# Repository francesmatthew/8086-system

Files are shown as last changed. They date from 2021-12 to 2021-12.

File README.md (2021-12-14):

# 8086-system
8086-based system, designed in KiCAD

3D Render of PCB

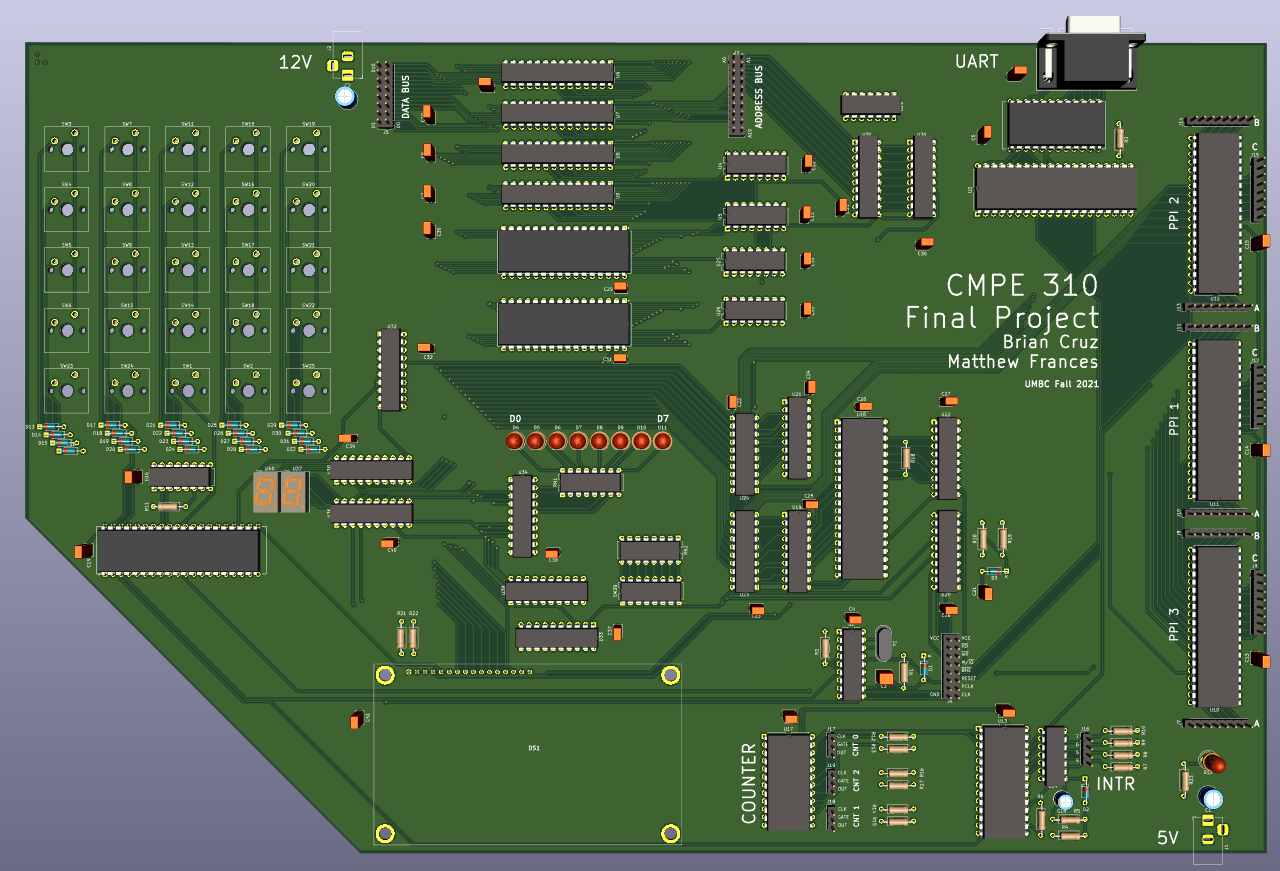
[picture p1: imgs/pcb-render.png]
PCB 3D Render


PCB Overview (fill zones not shown)

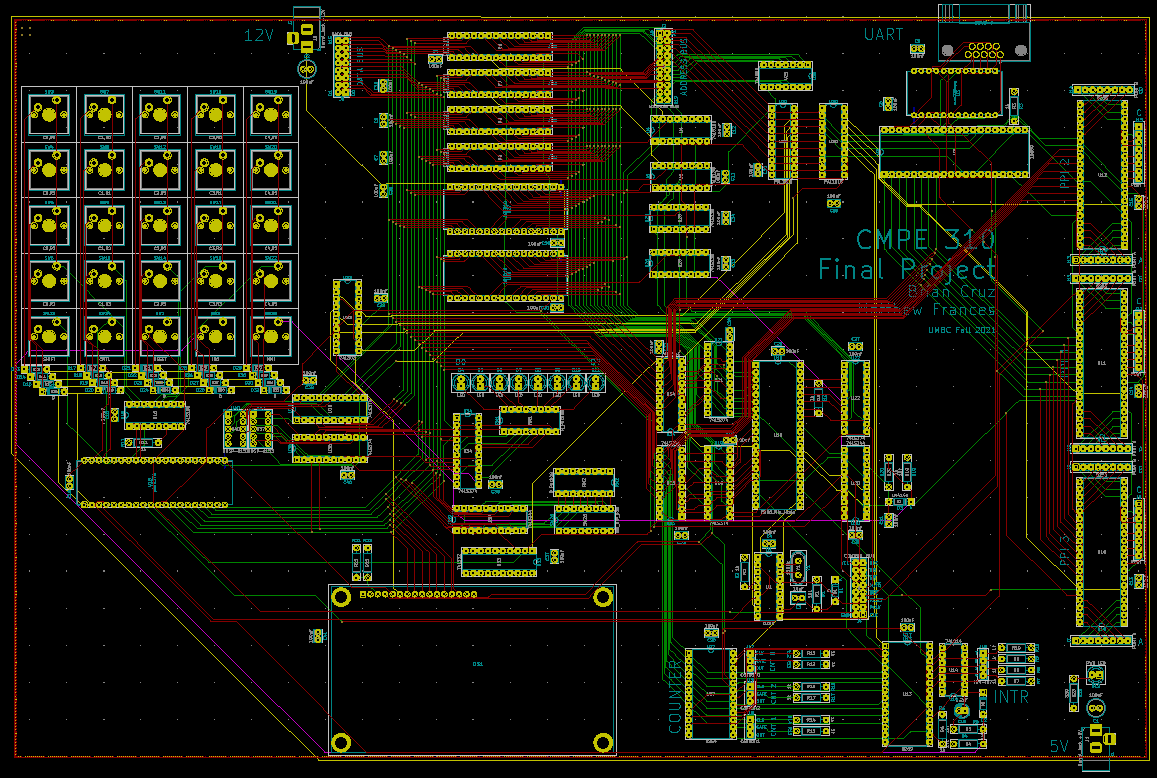
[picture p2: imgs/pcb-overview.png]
PCB Overview


Root Sheet

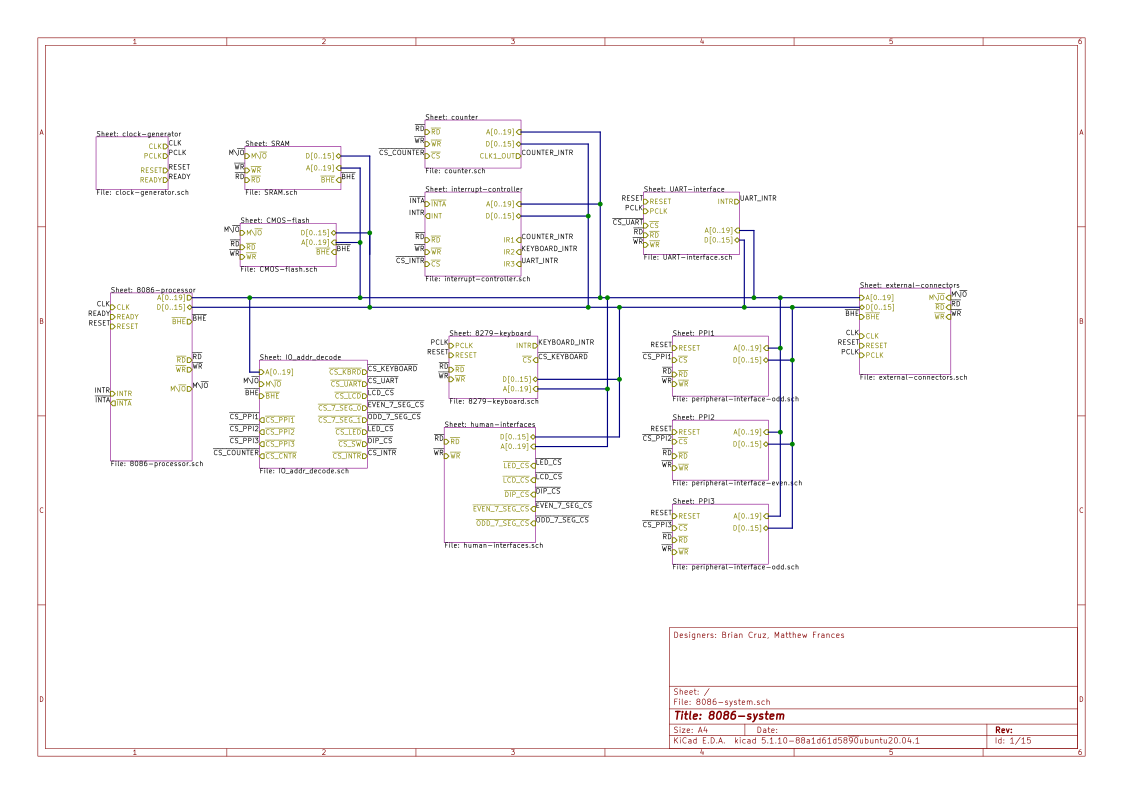
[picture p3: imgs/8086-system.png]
Root Sheet


8086 Processor and Bus Demultiplexing Logic

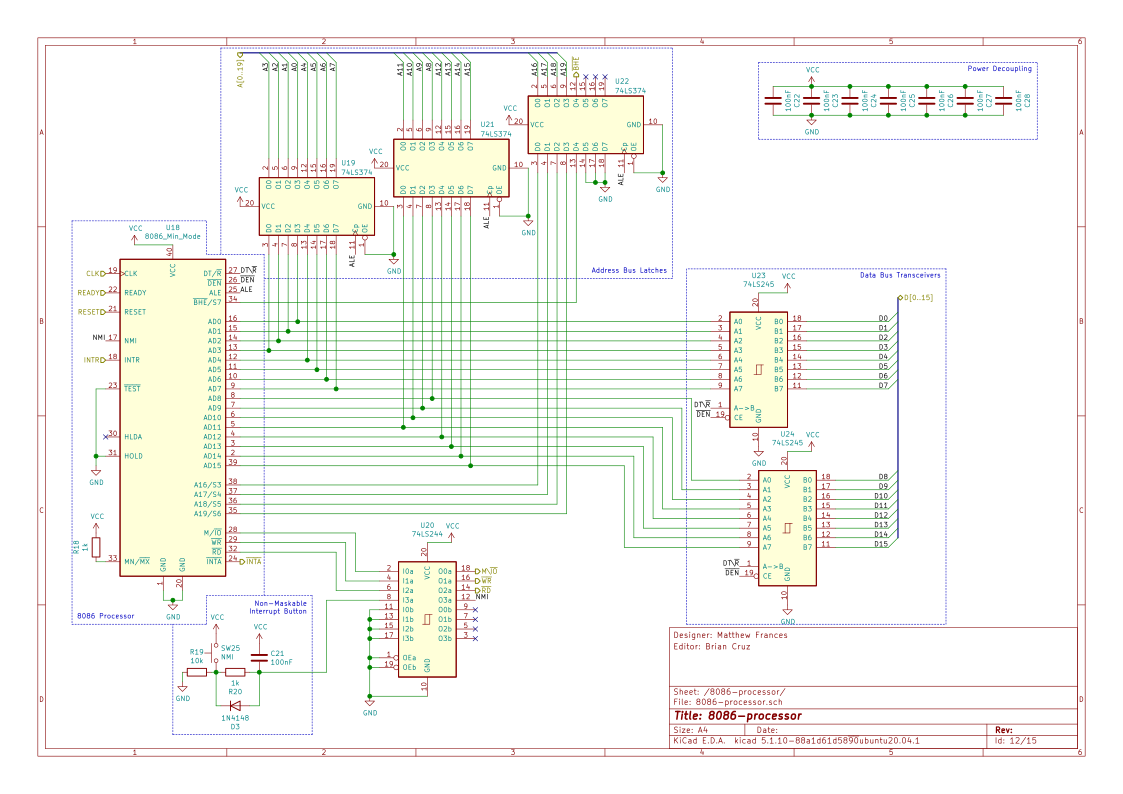
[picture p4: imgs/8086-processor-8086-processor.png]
8086 Processor


28F010 CMOS Flash

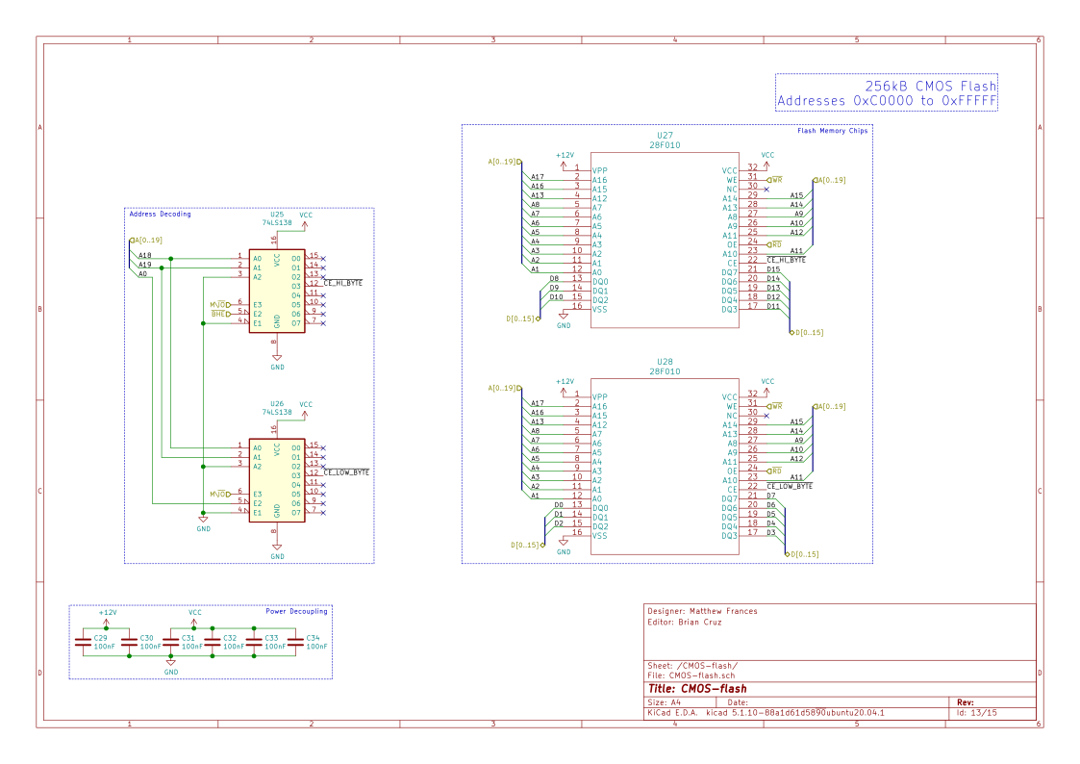
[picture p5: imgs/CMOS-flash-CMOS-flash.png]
28F010 CMOS Flash


CY7C199 SRAM

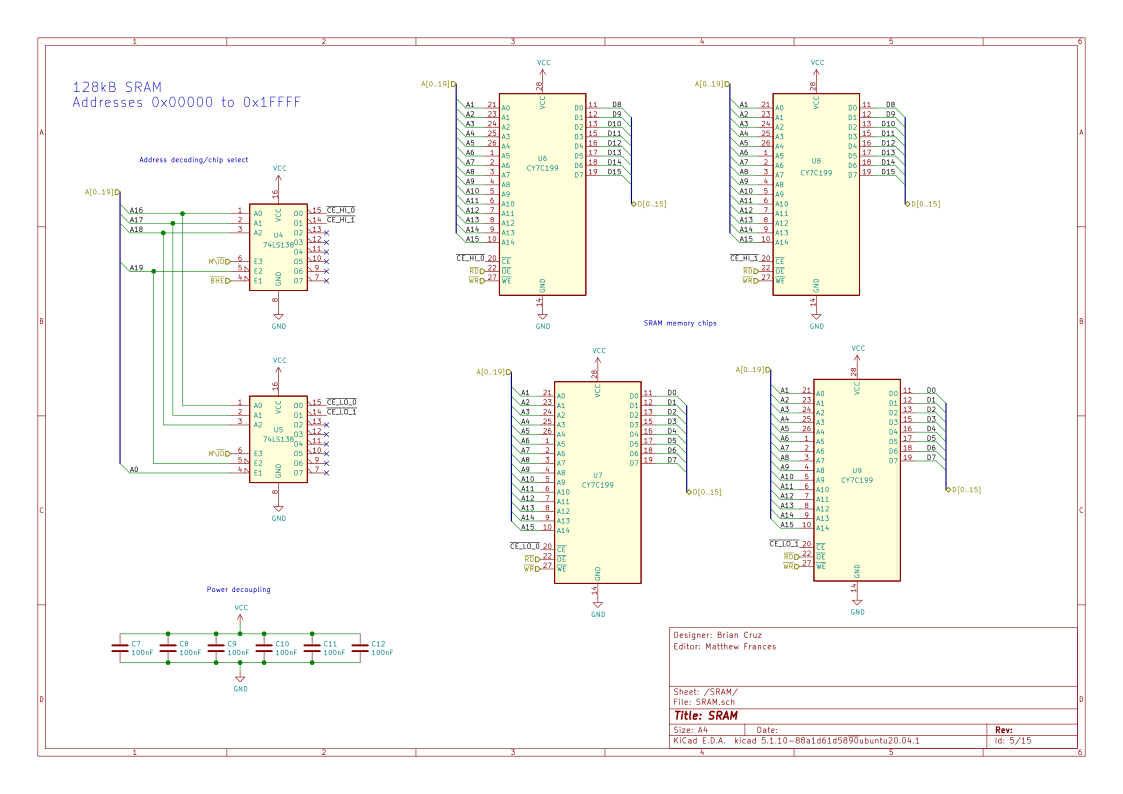
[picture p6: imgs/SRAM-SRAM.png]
CY7C199 SRAM


8284A Clock Generator

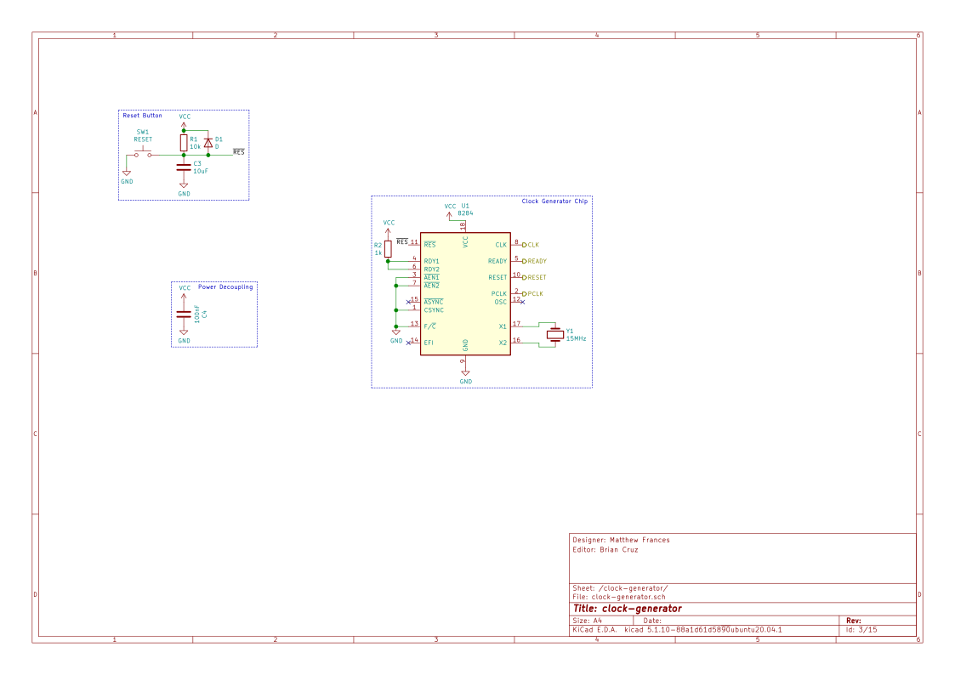
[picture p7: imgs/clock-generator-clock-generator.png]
8284A Clock Generator


PAL16L8 I/O Address Decoding

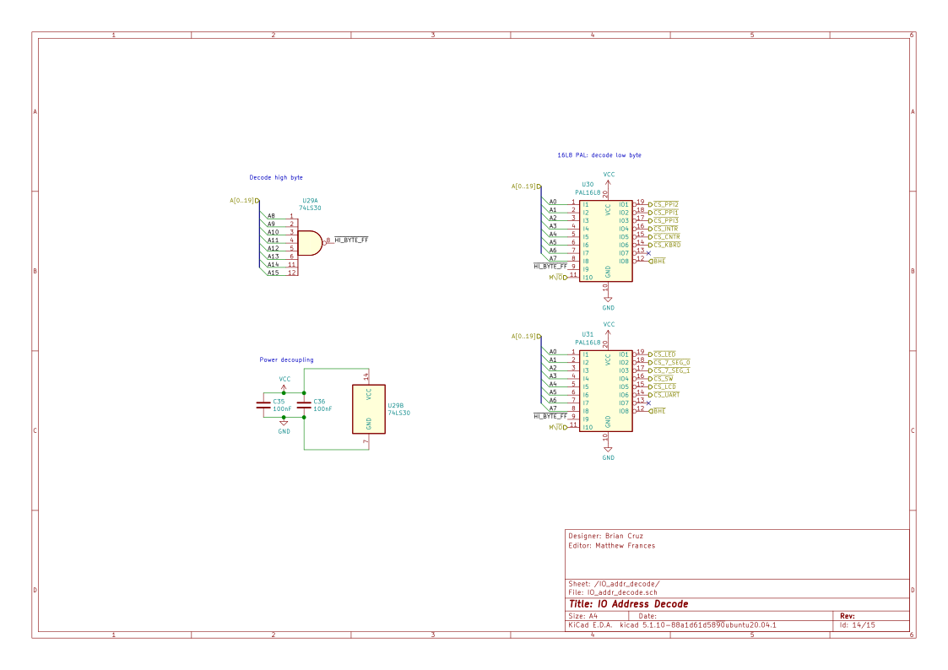
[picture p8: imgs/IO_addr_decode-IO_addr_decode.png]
PAL16L8 I/O Address Decoding


8259 Interrupt Controller

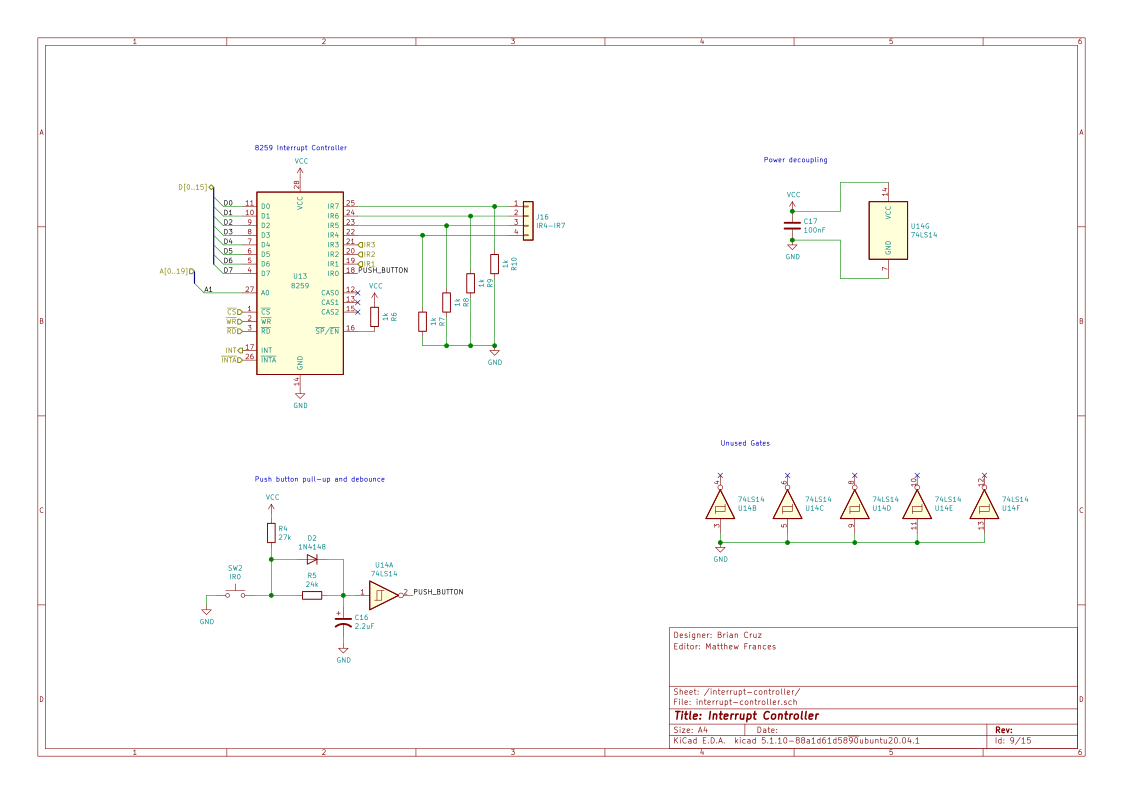
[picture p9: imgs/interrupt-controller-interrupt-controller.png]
8259 Interrupt Controller


8254 Counter

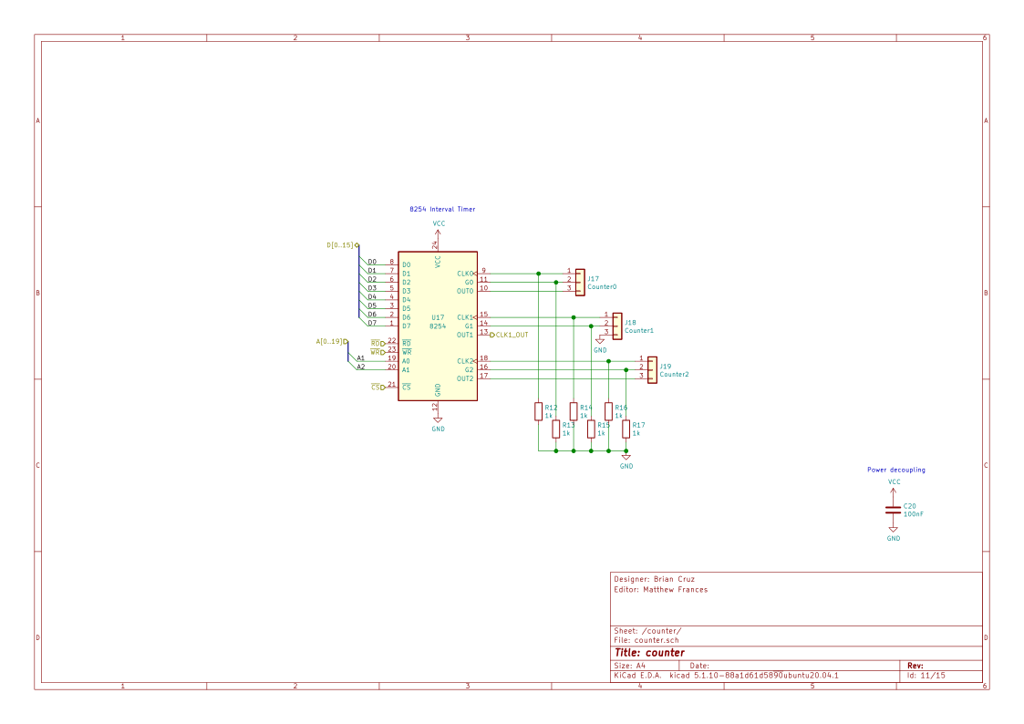
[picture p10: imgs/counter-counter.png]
8254 Counter


8279 Keyboard

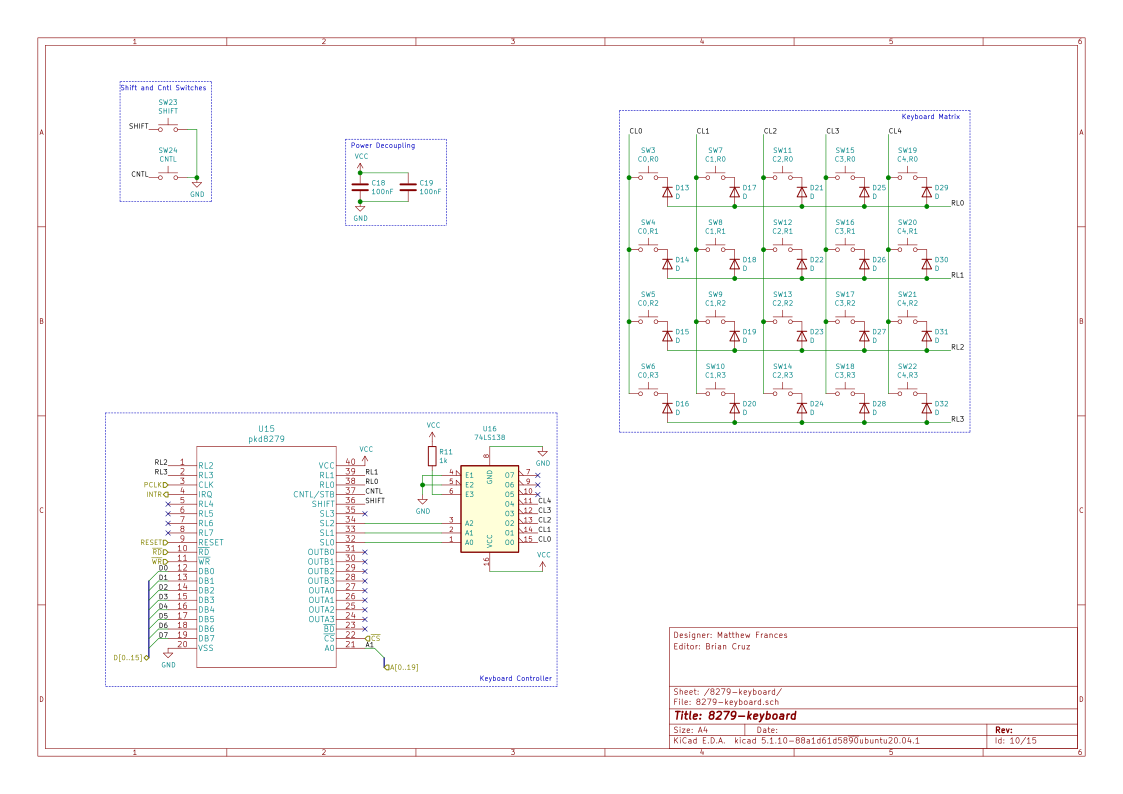
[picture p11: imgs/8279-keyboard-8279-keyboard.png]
8279 Keyboard


16550 UART Interface

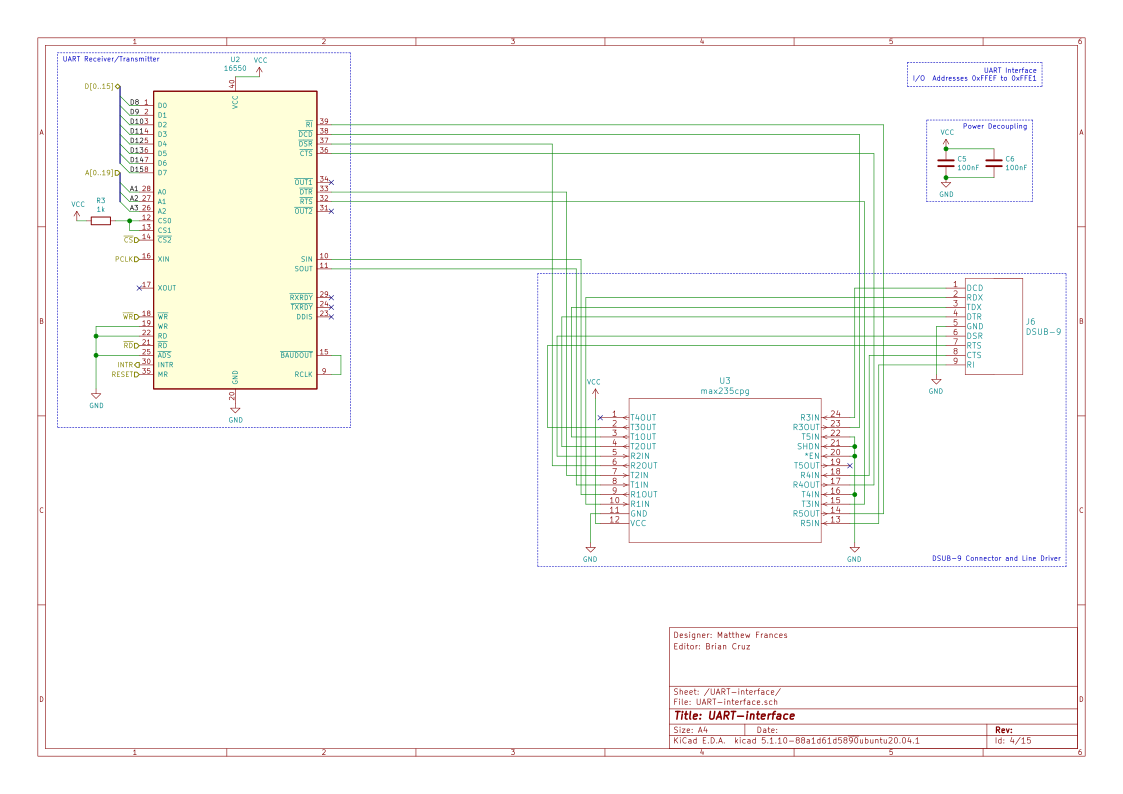
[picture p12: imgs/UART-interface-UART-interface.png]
16550 UART Interface


8255 Programmable Peripheral Interface 1

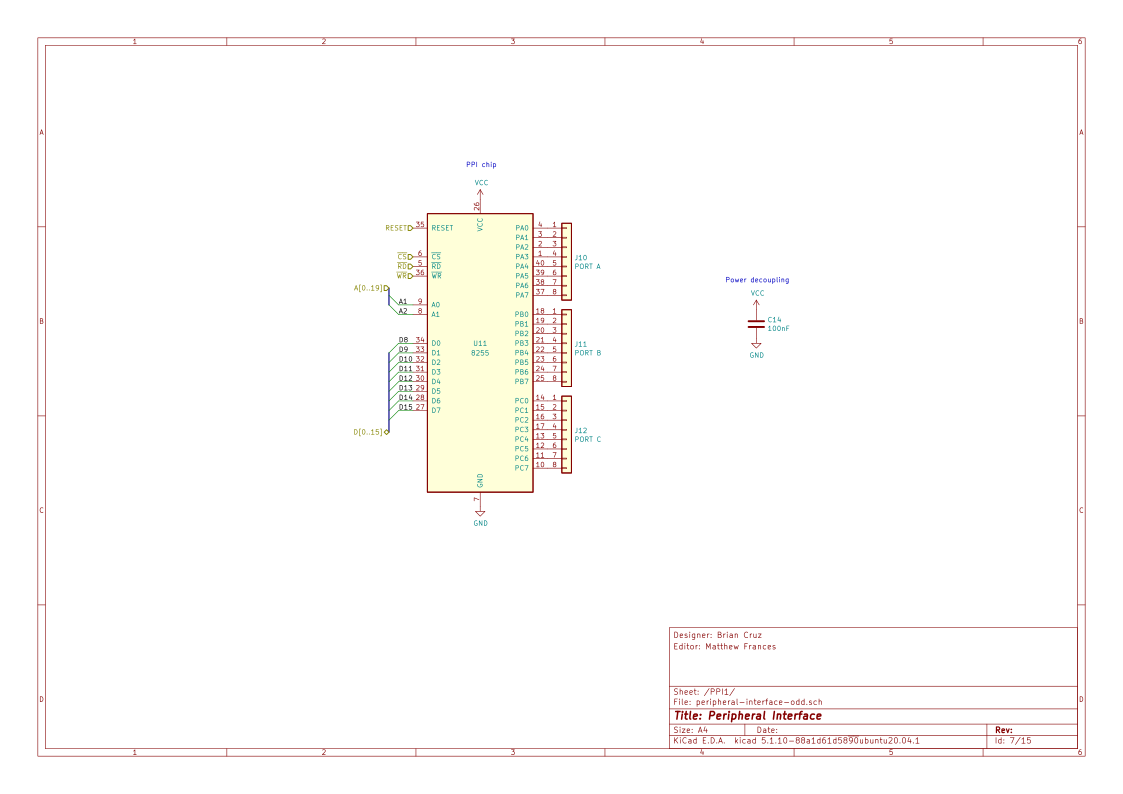
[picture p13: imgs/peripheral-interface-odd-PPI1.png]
8255 Programmable Peripheral Interface 1


8255 Programmable Peripheral Interface 2

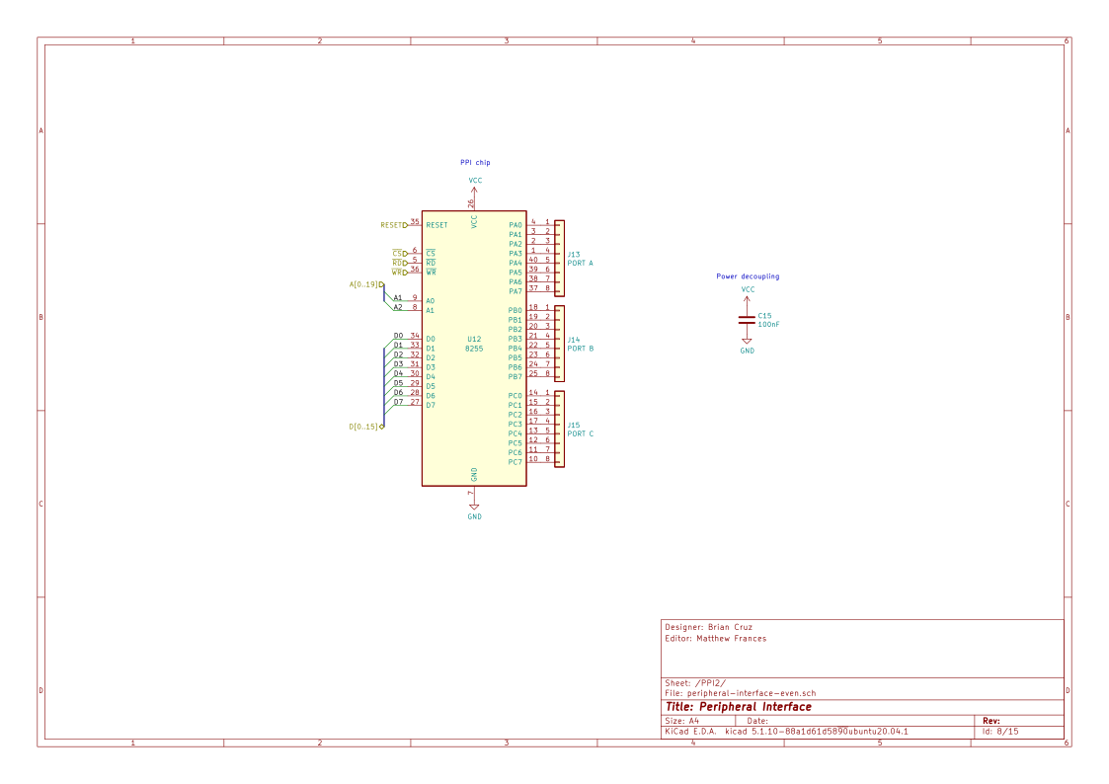
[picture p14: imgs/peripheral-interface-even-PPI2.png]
8255 Programmable Peripheral Interface 2


8255 Programmable Peripheral Interface 3

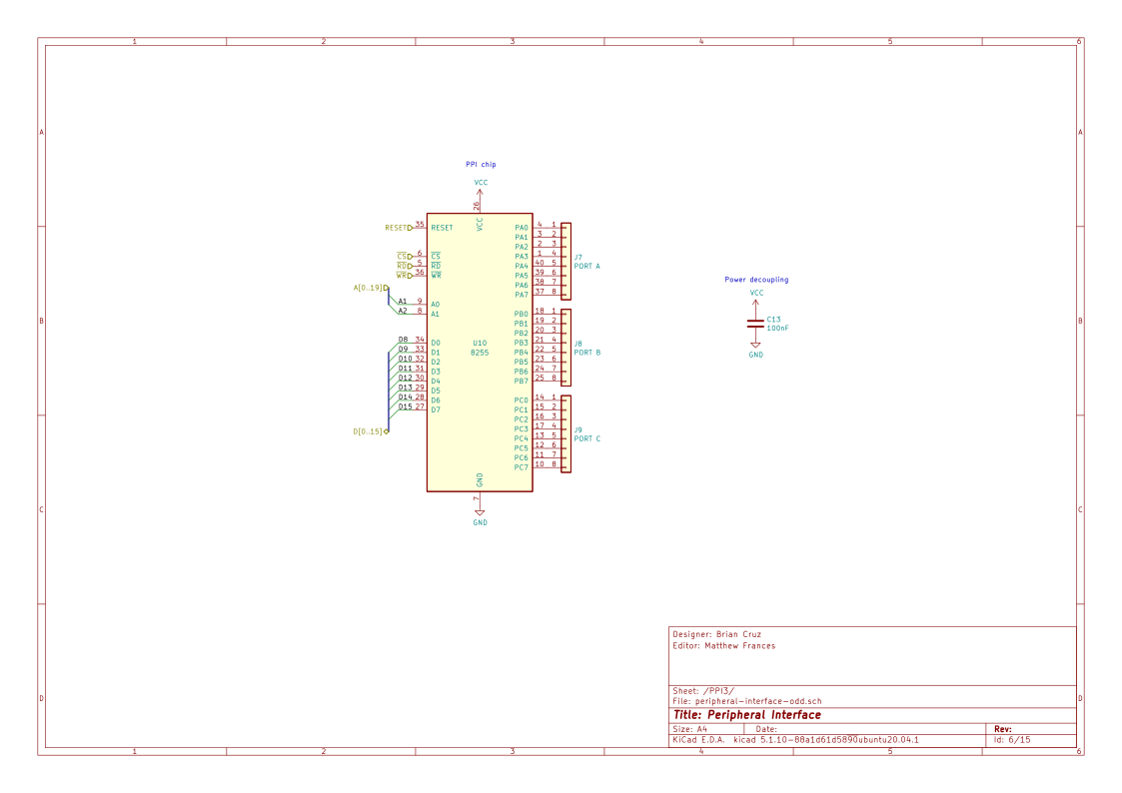
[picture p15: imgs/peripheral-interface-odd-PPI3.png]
8255 Programmable Peripheral Interface 3


LCD, 7-Segment Displays, LEDs, DIP Switches

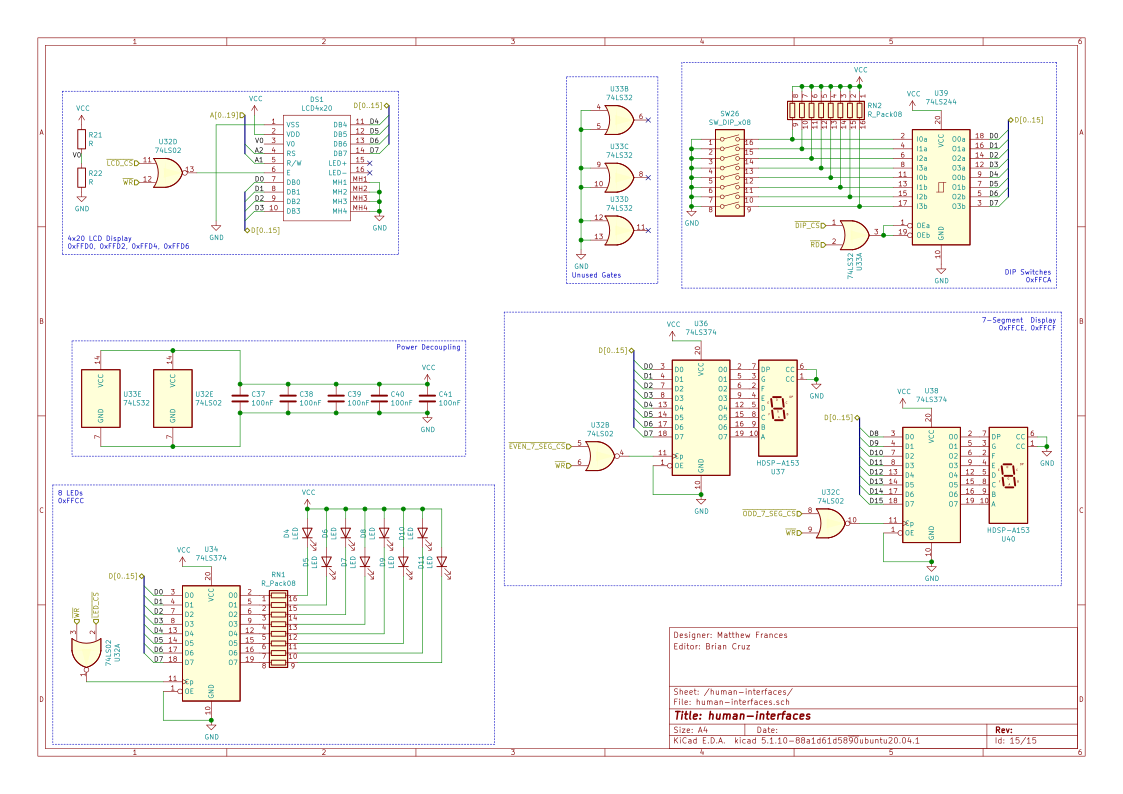
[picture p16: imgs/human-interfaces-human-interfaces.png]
LCD, 7-Segment Displays, LEDs, DIP Switches


Bus Headers, Power Connections

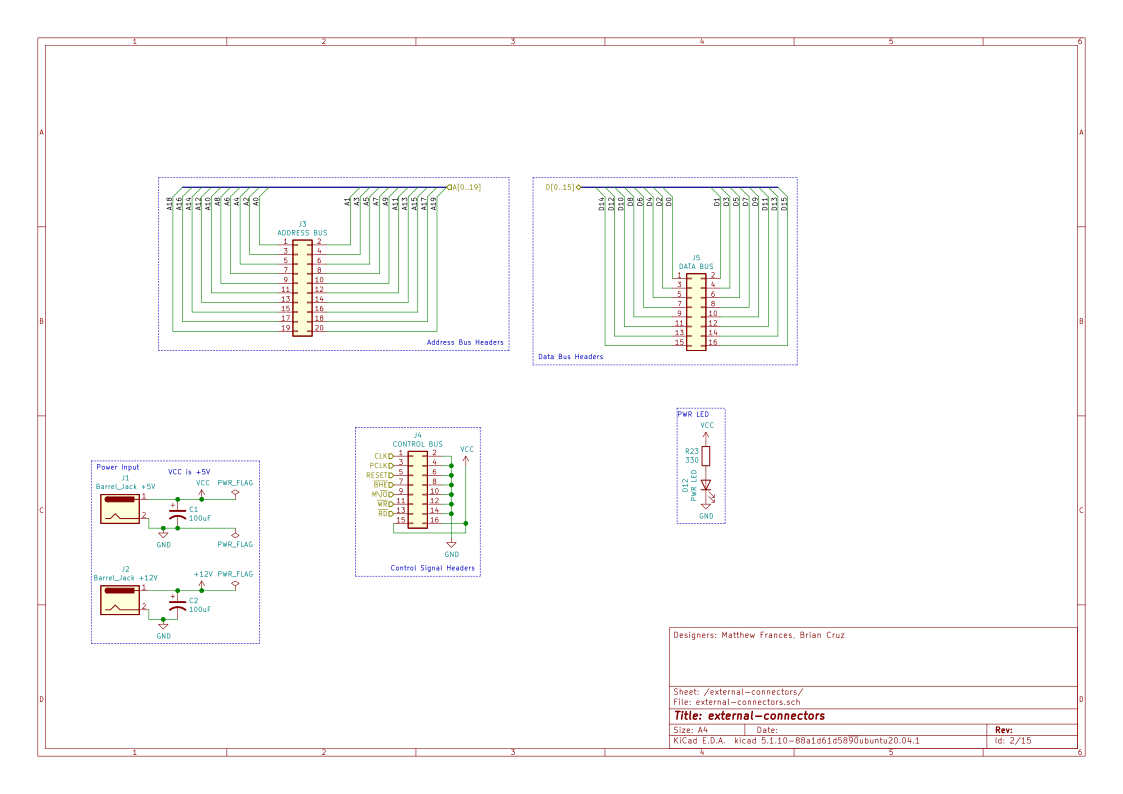
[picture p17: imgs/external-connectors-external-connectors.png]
Bus Headers, Power Connections


Front Copper Layer

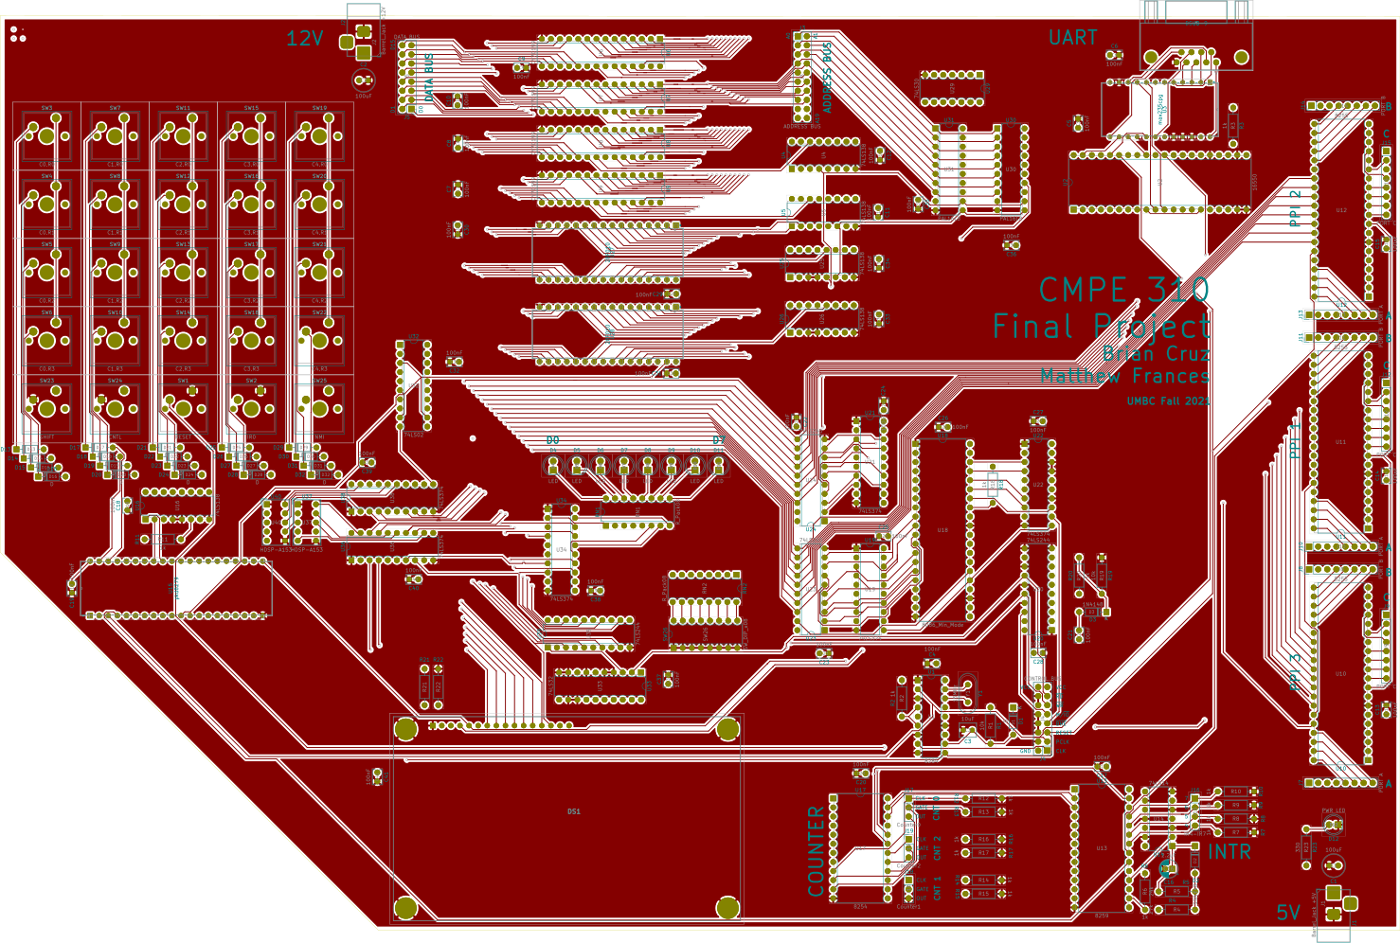
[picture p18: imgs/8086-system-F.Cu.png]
Front Copper Layer


Inner Copper Layer 1

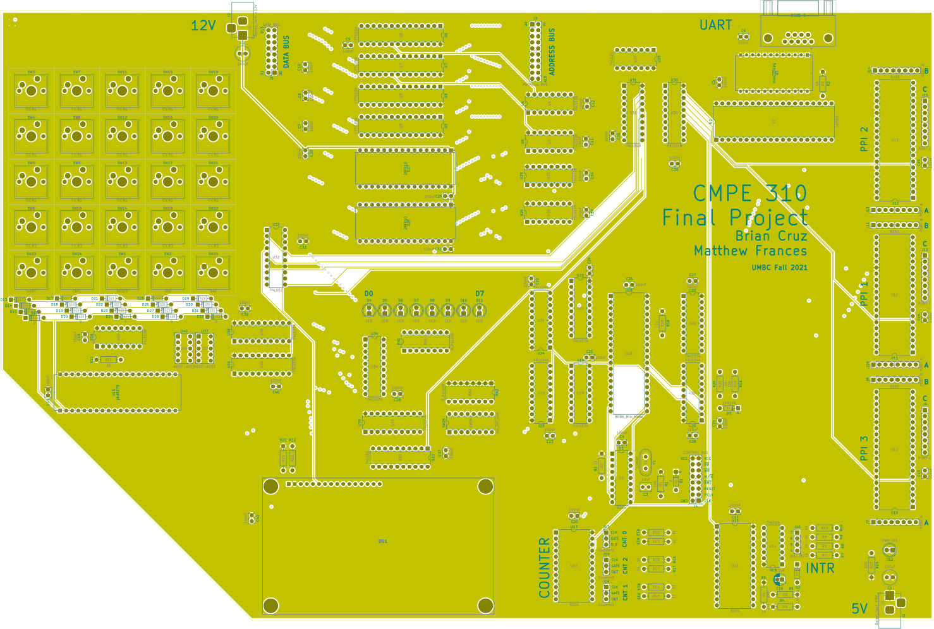
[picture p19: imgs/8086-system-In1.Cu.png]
Inner Copper Layer 1


Inner Copper Layer 2

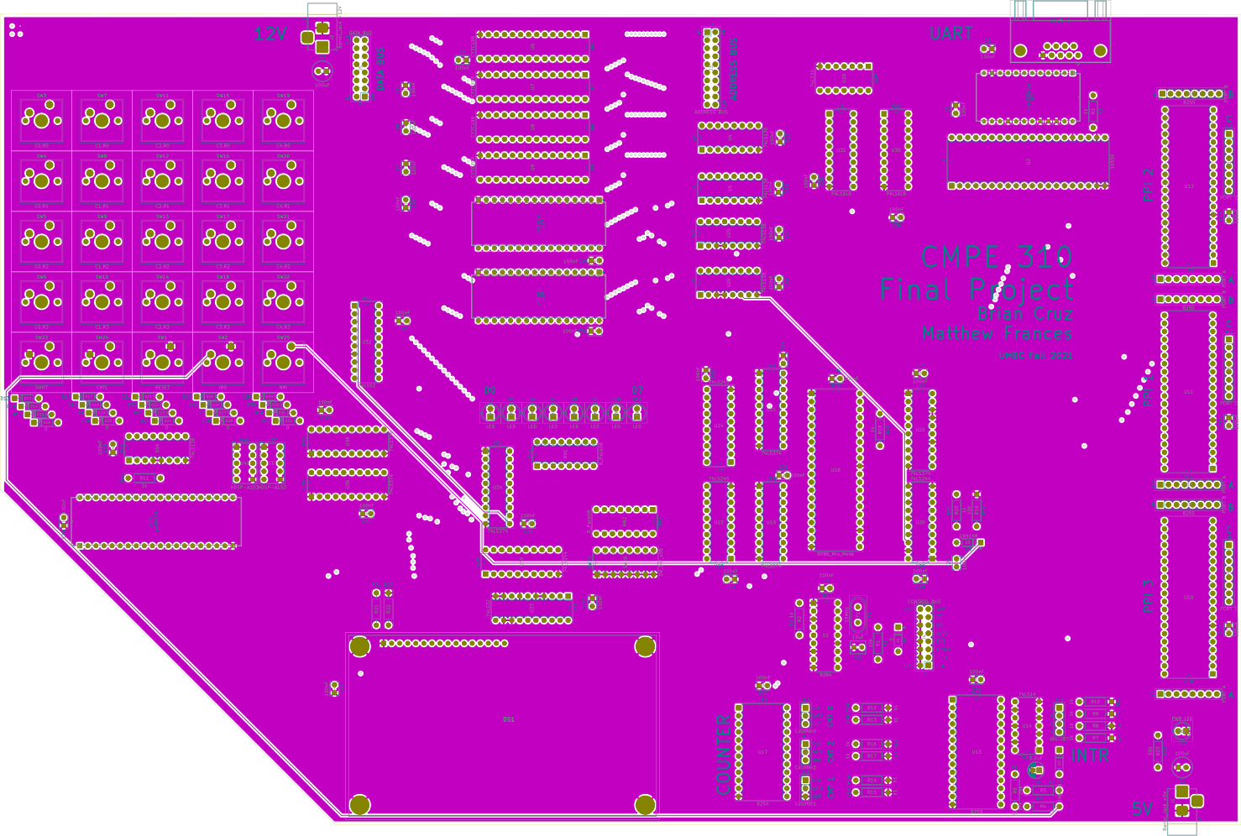
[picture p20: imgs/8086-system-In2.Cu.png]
Inner Copper Layer 2


Back Copper Layer

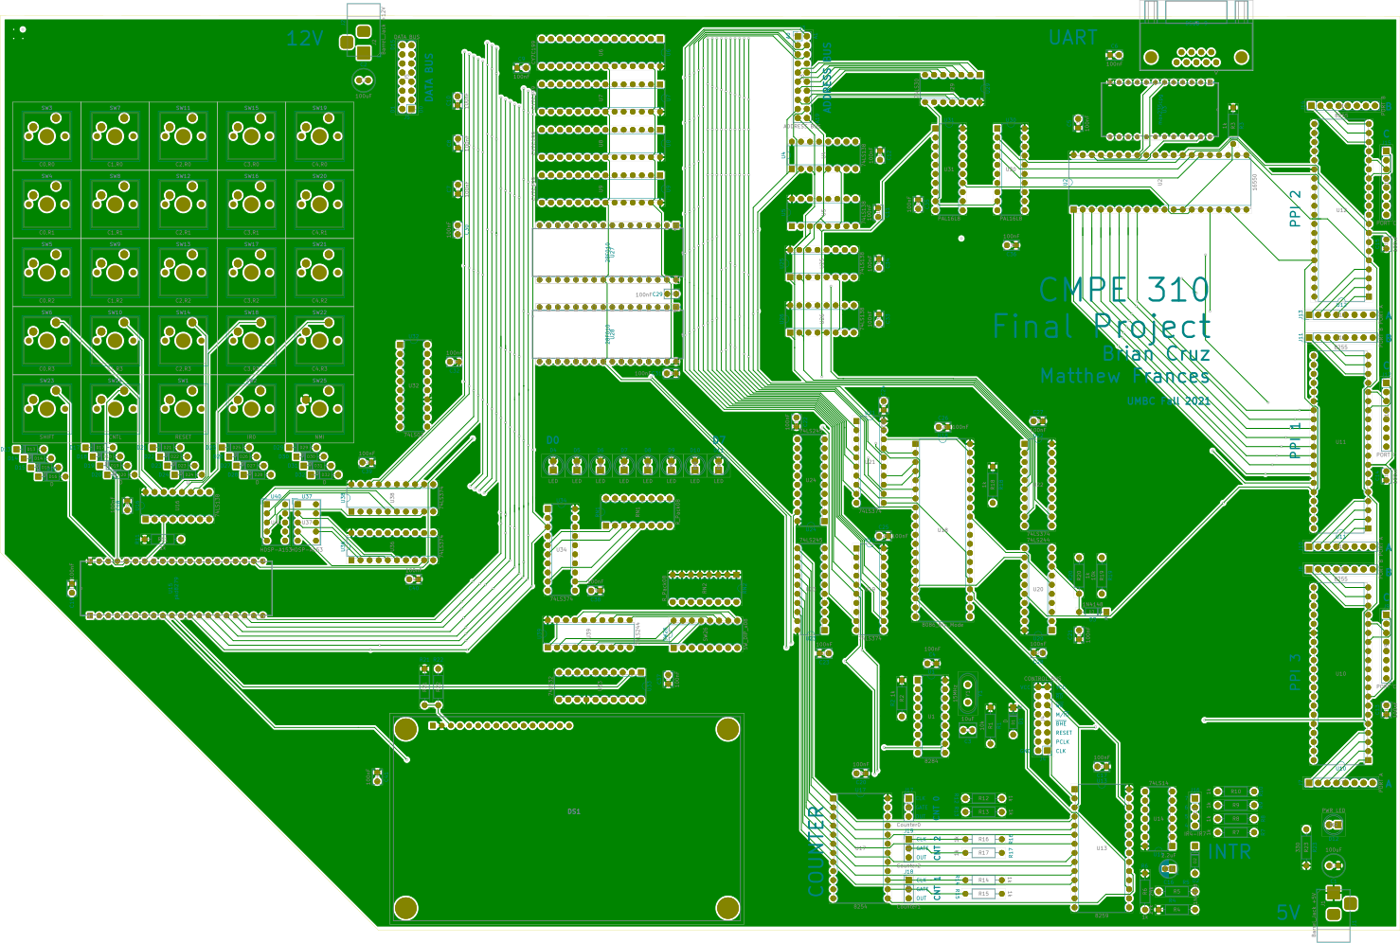
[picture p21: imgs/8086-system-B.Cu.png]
Back Copper Layer


This repository is for submission as the final project for Systems Design and Programming at the University of Maryland, Baltimore County under instruction of William Smith

Unauthorized copying of this project is considered a violation of university academic integrity policy

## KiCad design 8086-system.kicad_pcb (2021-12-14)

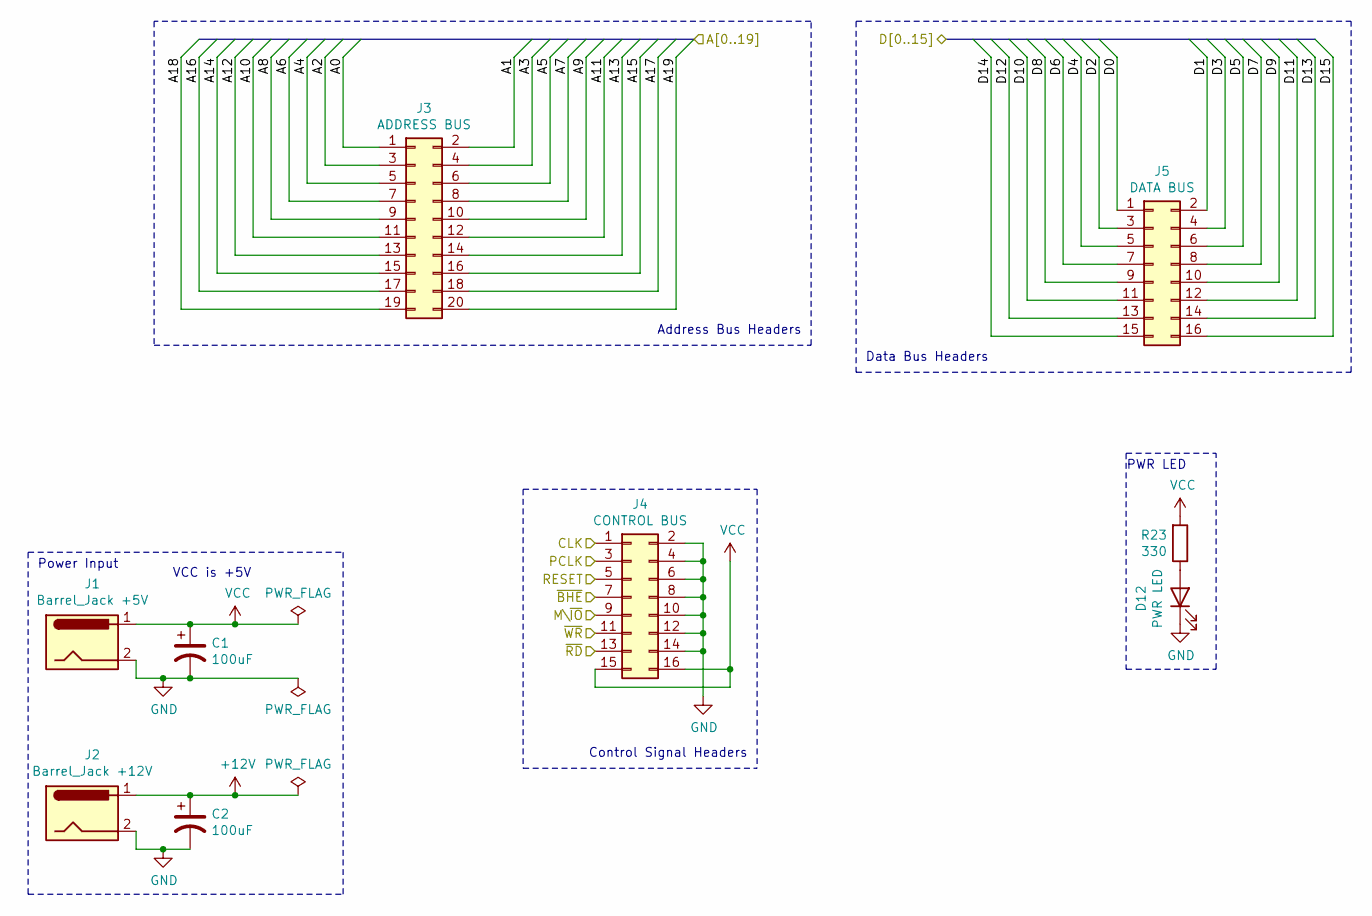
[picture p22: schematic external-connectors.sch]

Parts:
C1, C2: 100uF; C_Radial_D6.3mm_H5.0mm_P2.50mm
D12: PWR LED; LED_D5.0mm
J1: Barrel_Jack +5V; BarrelJack_Horizontal
J2: Barrel_Jack +12V; BarrelJack_Horizontal
J3: ADDRESS BUS; PinHeader_2x10_P2.54mm_Vertical
J4: CONTROL BUS; PinHeader_2x08_P2.54mm_Vertical
J5: DATA BUS; PinHeader_2x08_P2.54mm_Vertical
R23: 330; R_Axial_DIN0207_L6.3mm_D2.5mm_P10.16mm_Horizontal

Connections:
+12V: C2.1, J2.1; also elsewhere on the board
/8086-processor/A0: J3.1; also elsewhere on the board
/8086-processor/A1: J3.2; also elsewhere on the board
/8086-processor/A2: J3.3; also elsewhere on the board
/8086-processor/A3: J3.4; also elsewhere on the board
/8086-processor/A4: J3.5; also elsewhere on the board
/8086-processor/A5: J3.6; also elsewhere on the board
/8086-processor/A6: J3.7; also elsewhere on the board
/8086-processor/A7: J3.8; also elsewhere on the board
/8086-processor/A8: J3.9; also elsewhere on the board
/8086-processor/A9: J3.10; also elsewhere on the board
/8086-processor/A10: J3.11; also elsewhere on the board
/8086-processor/A11: J3.12; also elsewhere on the board
/8086-processor/A12: J3.13; also elsewhere on the board
/8086-processor/A13: J3.14; also elsewhere on the board
/8086-processor/A14: J3.15; also elsewhere on the board
/8086-processor/A15: J3.16; also elsewhere on the board
/8086-processor/A16: J3.17; also elsewhere on the board
/8086-processor/A17: J3.18; also elsewhere on the board
/8086-processor/A18: J3.19; also elsewhere on the board
/8086-processor/A19: J3.20; also elsewhere on the board
/8086-processor/D0: J5.1; also elsewhere on the board
/8086-processor/D1: J5.2; also elsewhere on the board
/8086-processor/D2: J5.3; also elsewhere on the board
/8086-processor/D3: J5.4; also elsewhere on the board
/8086-processor/D4: J5.5; also elsewhere on the board
/8086-processor/D5: J5.6; also elsewhere on the board
/8086-processor/D6: J5.7; also elsewhere on the board
/8086-processor/D7: J5.8; also elsewhere on the board
/8086-processor/D8: J5.9; also elsewhere on the board
/8086-processor/D9: J5.10; also elsewhere on the board
/8086-processor/D10: J5.11; also elsewhere on the board
/8086-processor/D11: J5.12; also elsewhere on the board
/8086-processor/D12: J5.13; also elsewhere on the board
/8086-processor/D13: J5.14; also elsewhere on the board
/8086-processor/D14: J5.15; also elsewhere on the board
/8086-processor/D15: J5.16; also elsewhere on the board
/CLK: J4.1; also elsewhere on the board
/M\~IO: J4.9; also elsewhere on the board
/PCLK: J4.3; also elsewhere on the board
/RESET: J4.5; also elsewhere on the board
/~BHE: J4.7; also elsewhere on the board
/~RD: J4.13; also elsewhere on the board
/~WR: J4.11; also elsewhere on the board
GND: C1.2, C2.2, D12.1 (K), J1.2, J2.2, J4.2, J4.4, J4.6, J4.8, J4.10, J4.12, J4.14; also elsewhere on the board
unnamed: D12.2 (A), R23.1
VCC: C1.1, J1.1, J4.15, J4.16, R23.2; also elsewhere on the board

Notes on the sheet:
Data Bus Headers
Address Bus Headers
Power Input
VCC is +5V
Control Signal Headers
PWR LED

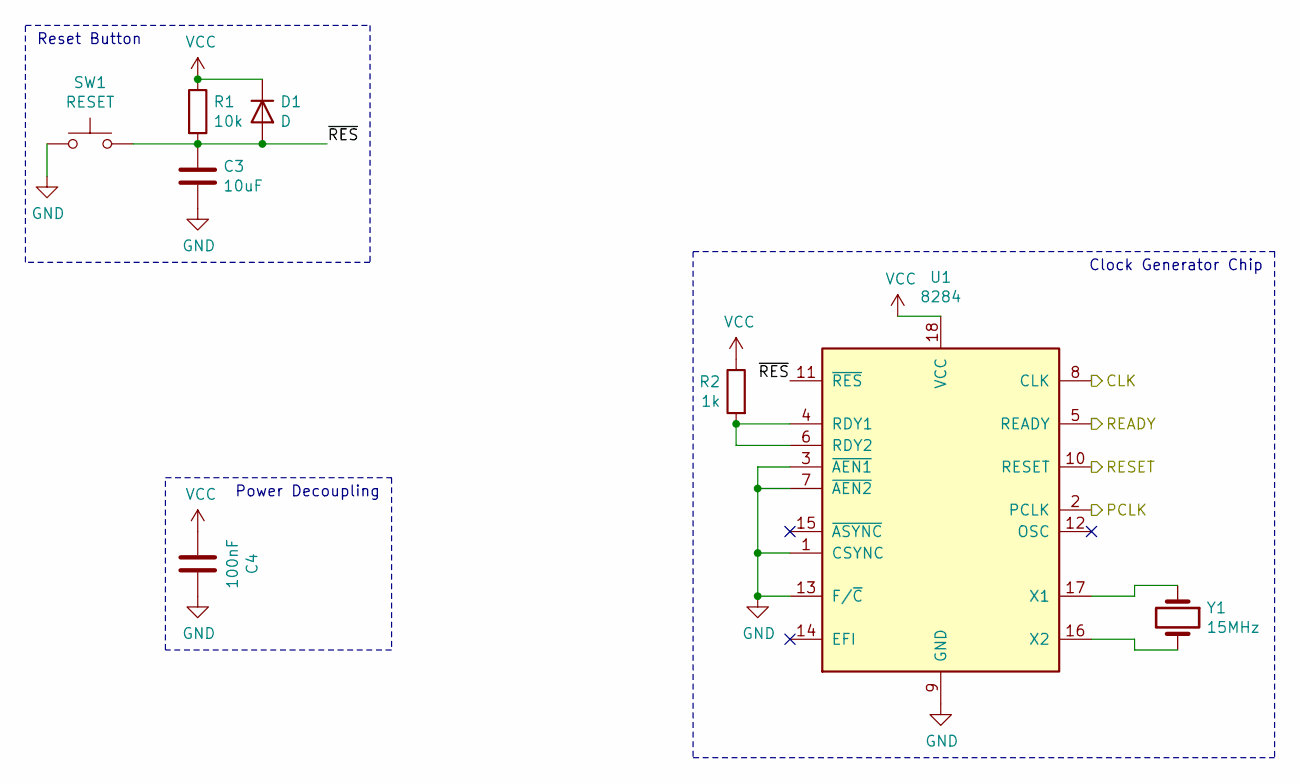
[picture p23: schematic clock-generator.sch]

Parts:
C3: 10uF; C_Rect_L4.6mm_W3.8mm_P2.50mm_MKS02_FKP02
C4: 100nF; C_Rect_L4.0mm_W2.5mm_P2.50mm
D1: D; D_DO-35_SOD27_P7.62mm_Horizontal
R1: 10k; R_Axial_DIN0207_L6.3mm_D2.5mm_P10.16mm_Horizontal
R2: 1k; R_Axial_DIN0207_L6.3mm_D2.5mm_P10.16mm_Horizontal
SW1: RESET; SW_Cherry_MX_1.00u_PCB
U1: 8284; DIP-18_W7.62mm
Y1: 15MHz; Crystal_HC49-4H_Vertical

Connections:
/CLK: U1.8 (CLK); also elsewhere on the board
/PCLK: U1.2 (PCLK); also elsewhere on the board
/READY: U1.5 (READY); also elsewhere on the board
/RESET: U1.10 (RESET); also elsewhere on the board
/clock-generator/~RES: C3.1, D1.2 (A), R1.2, SW1.2, U1.11 (~RES~)
GND: C3.2, C4.2, SW1.1, U1.1 (CSYNC), U1.3 (~AEN1~), U1.7 (~AEN2~), U1.9 (GND), U1.13 (F/~C~); also elsewhere on the board
unnamed: R2.2, U1.4 (RDY1), U1.6 (RDY2)
unnamed: U1.16 (X2), Y1.2
unnamed: U1.17 (X1), Y1.1
VCC: C4.1, D1.1 (K), R1.1, R2.1, U1.18 (VCC); also elsewhere on the board

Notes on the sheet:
Clock Generator Chip
Power Decoupling
Reset Button

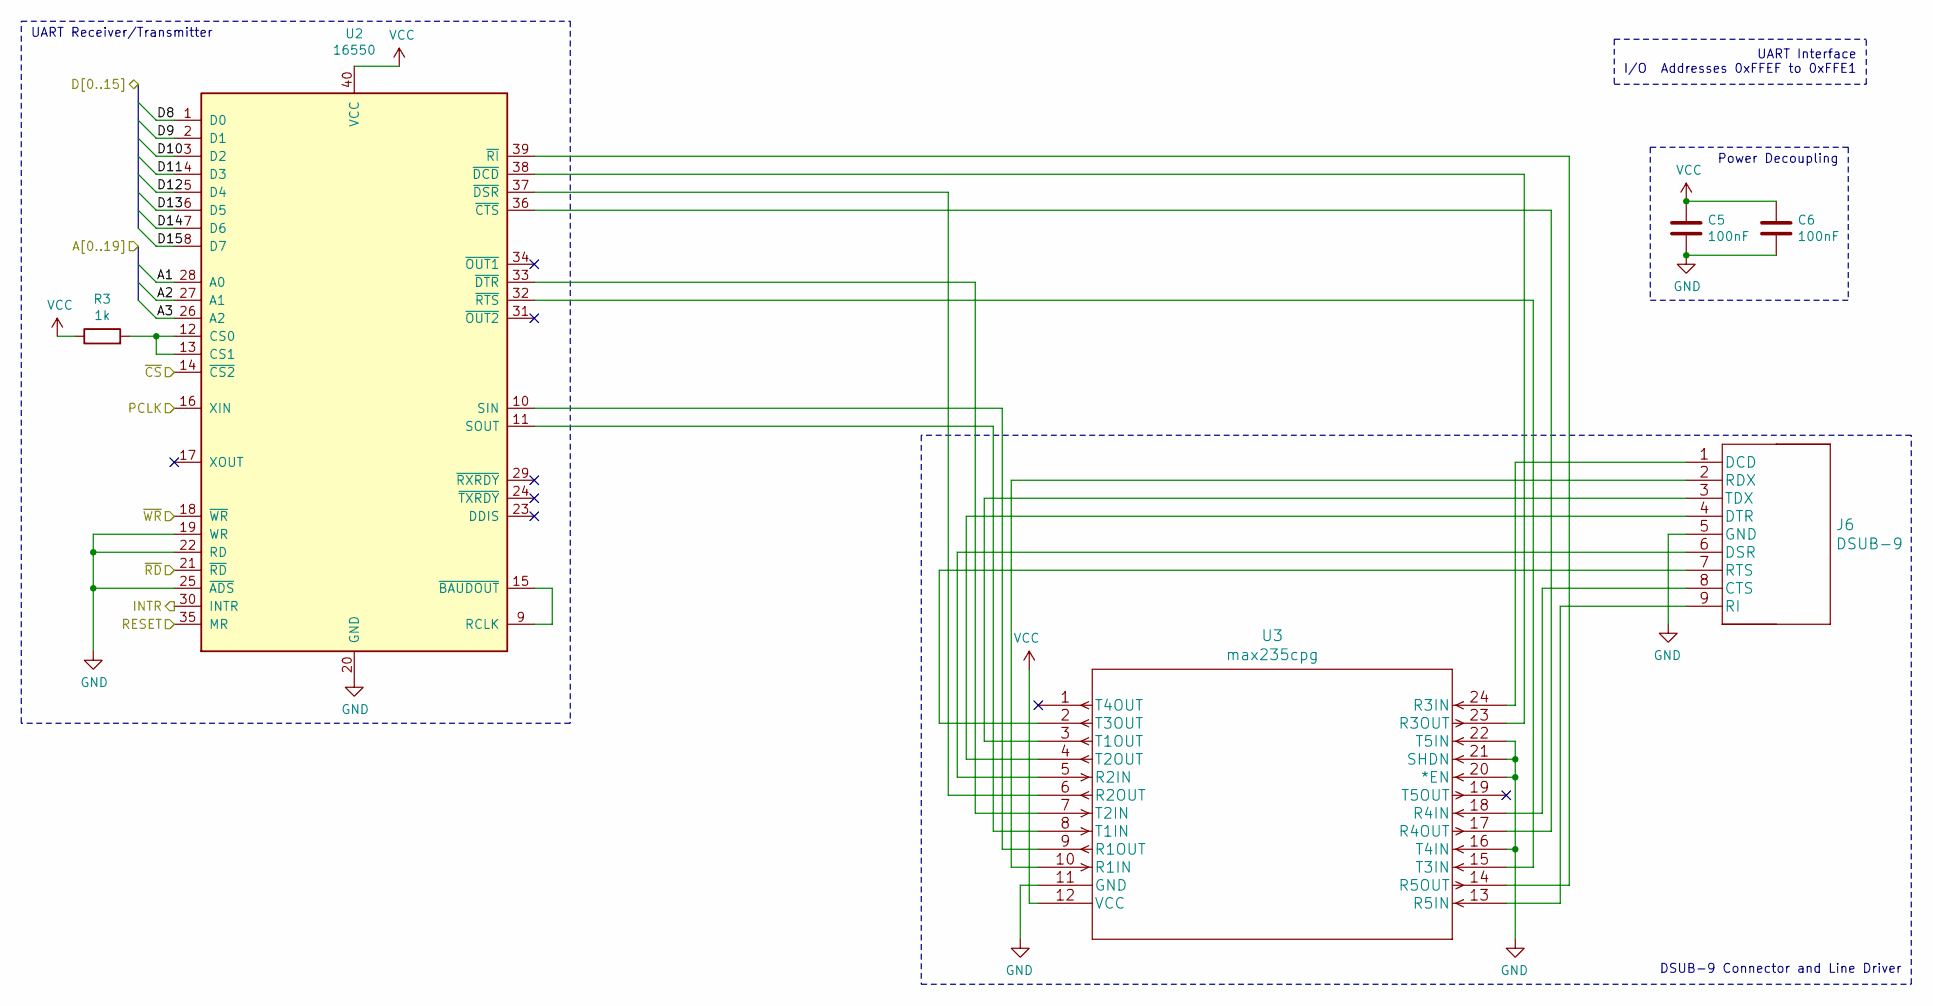
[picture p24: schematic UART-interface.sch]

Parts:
C5, C6: 100nF; C_Rect_L4.0mm_W2.5mm_P2.50mm
J6: DSUB-9
R3: 1k; R_Axial_DIN0207_L6.3mm_D2.5mm_P10.16mm_Horizontal
U2: 16550; DIP-40_W15.24mm
U3: max235cpg

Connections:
/8086-processor/A1: U2.28 (A0); also elsewhere on the board
/8086-processor/A2: U2.27 (A1); also elsewhere on the board
/8086-processor/A3: U2.26 (A2); also elsewhere on the board
/8086-processor/D8: U2.1 (D0); also elsewhere on the board
/8086-processor/D9: U2.2 (D1); also elsewhere on the board
/8086-processor/D10: U2.3 (D2); also elsewhere on the board
/8086-processor/D11: U2.4 (D3); also elsewhere on the board
/8086-processor/D12: U2.5 (D4); also elsewhere on the board
/8086-processor/D13: U2.6 (D5); also elsewhere on the board
/8086-processor/D14: U2.7 (D6); also elsewhere on the board
/8086-processor/D15: U2.8 (D7); also elsewhere on the board
/PCLK: U2.16 (XIN); also elsewhere on the board
/RESET: U2.35 (MR); also elsewhere on the board
/UART_INTR: U2.30 (INTR); also elsewhere on the board
/~CS_UART: U2.14 (~CS2~); also elsewhere on the board
/~RD: U2.21 (~RD~); also elsewhere on the board
/~WR: U2.18 (~WR~); also elsewhere on the board
GND: C5.2, C6.2, J6.5 (GND), U2.19 (WR), U2.20 (GND), U2.22 (RD), U2.25 (~ADS~), U3.11 (GND), U3.16 (T4IN), U3.20 (*EN), U3.21 (SHDN), U3.22 (T5IN); also elsewhere on the board
unnamed: J6.1 (DCD), U3.24 (R3IN)
unnamed: J6.2 (RDX), U3.10 (R1IN)
unnamed: J6.3 (TDX), U3.3 (T1OUT)
unnamed: J6.4 (DTR), U3.4 (T2OUT)
unnamed: J6.6 (DSR), U3.5 (R2IN)
unnamed: J6.7 (RTS), U3.2 (T3OUT)
unnamed: J6.8 (CTS), U3.18 (R4IN)
unnamed: J6.9 (RI), U3.13 (R5IN)
unnamed: R3.2, U2.12 (CS0), U2.13 (CS1)
unnamed: U2.10 (SIN), U3.9 (R1OUT)
unnamed: U2.11 (SOUT), U3.8 (T1IN)
unnamed: U2.9 (RCLK), U2.15 (~BAUDOUT~)
unnamed: U2.32 (~RTS~), U3.15 (T3IN)
unnamed: U2.33 (~DTR~), U3.7 (T2IN)
unnamed: U2.36 (~CTS~), U3.17 (R4OUT)
unnamed: U2.37 (~DSR~), U3.6 (R2OUT)
unnamed: U2.38 (~DCD~), U3.23 (R3OUT)
unnamed: U2.39 (~RI~), U3.14 (R5OUT)
VCC: C5.1, C6.1, R3.1, U2.40 (VCC), U3.12 (VCC); also elsewhere on the board

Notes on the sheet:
UART Interface I/O Addresses 0xFFEF to 0xFFE1
UART Receiver/Transmitter
Power Decoupling
DSUB-9 Connector and Line Driver

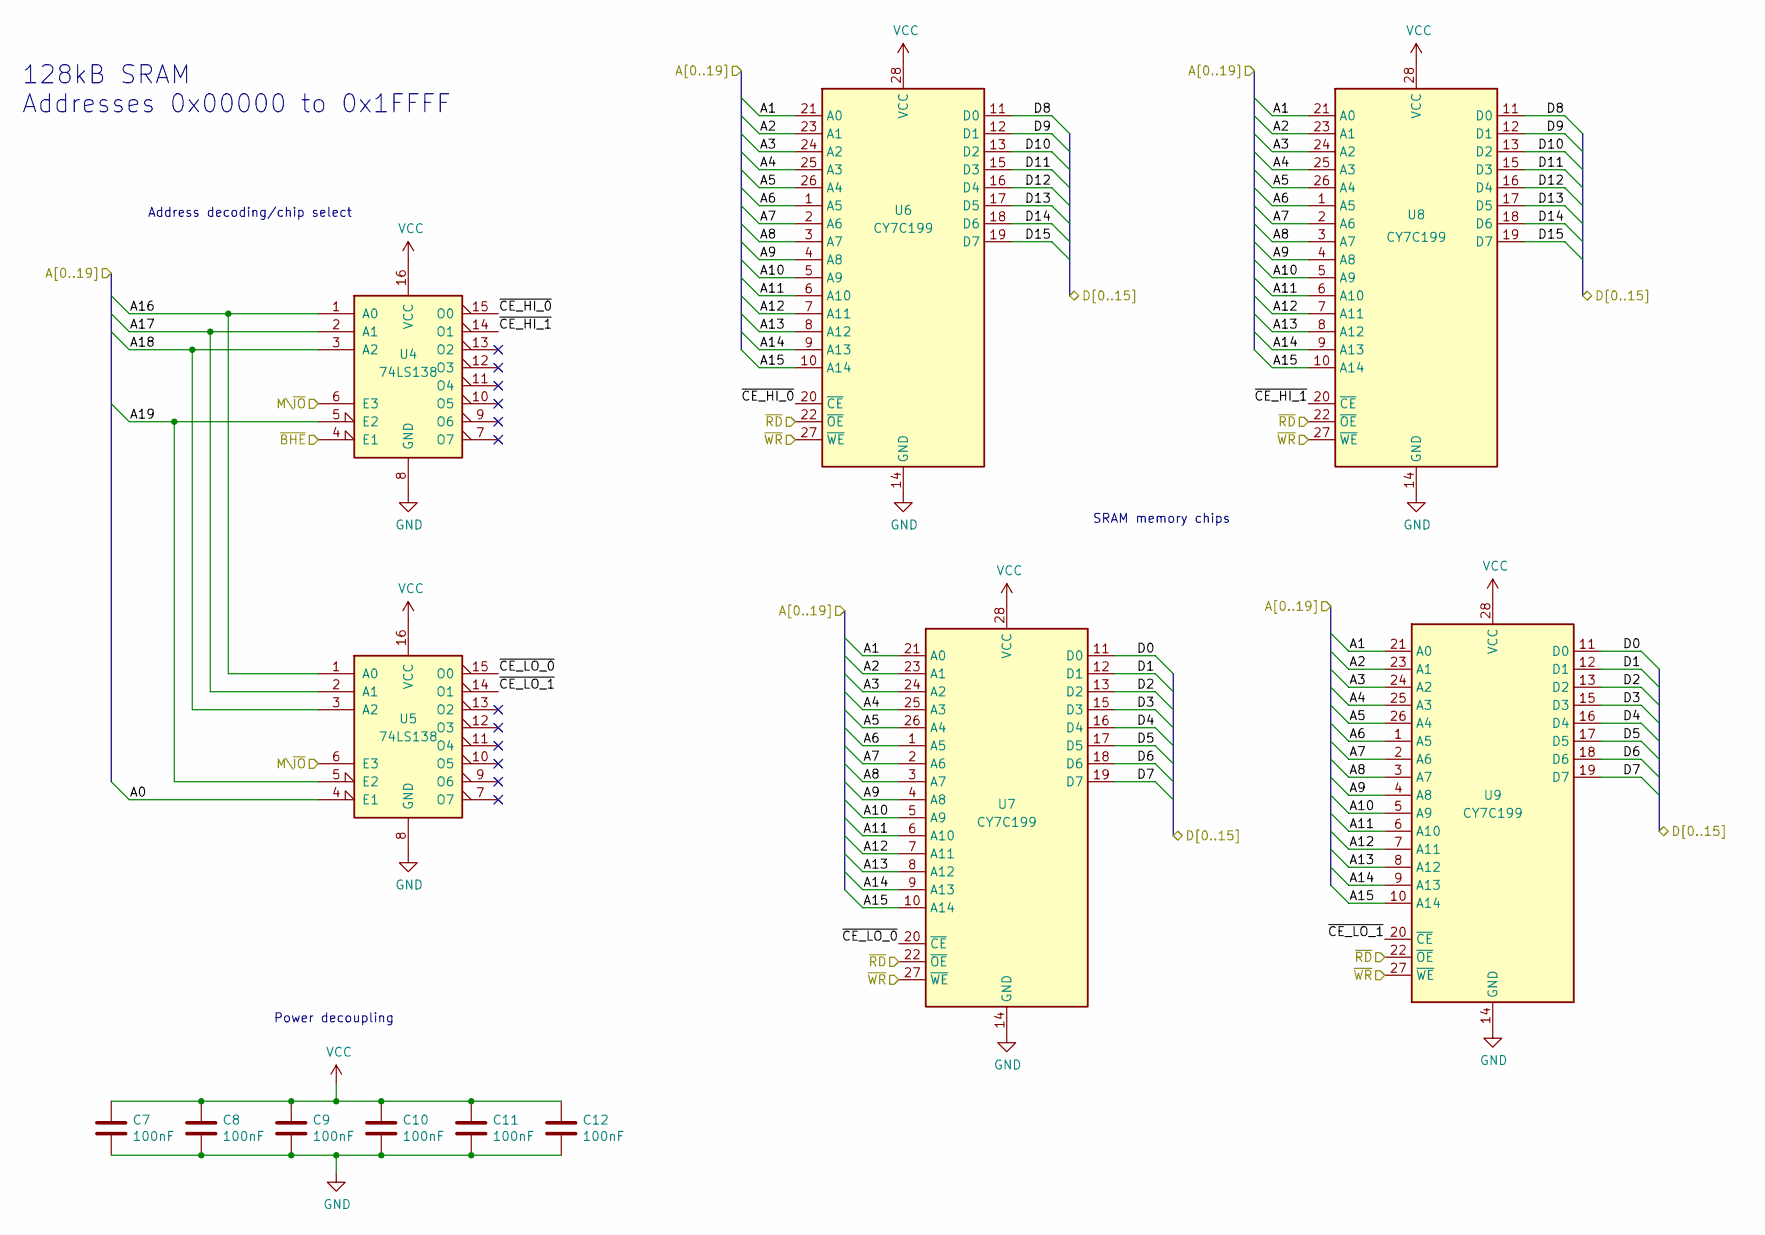
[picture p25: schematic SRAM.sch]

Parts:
C7, C8, C9, C10, C11, C12: 100nF; C_Rect_L4.0mm_W2.5mm_P2.50mm
U4, U5: 74LS138; DIP-16_W7.62mm
U6, U7, U8, U9: CY7C199; DIP-28_W7.62mm

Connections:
/8086-processor/A0: U5.4 (E1); also elsewhere on the board
/8086-processor/A1: U6.21 (A0), U7.21 (A0), U8.21 (A0), U9.21 (A0); also elsewhere on the board
/8086-processor/A2: U6.23 (A1), U7.23 (A1), U8.23 (A1), U9.23 (A1); also elsewhere on the board
/8086-processor/A3: U6.24 (A2), U7.24 (A2), U8.24 (A2), U9.24 (A2); also elsewhere on the board
/8086-processor/A4: U6.25 (A3), U7.25 (A3), U8.25 (A3), U9.25 (A3); also elsewhere on the board
/8086-processor/A5: U6.26 (A4), U7.26 (A4), U8.26 (A4), U9.26 (A4); also elsewhere on the board
/8086-processor/A6: U6.1 (A5), U7.1 (A5), U8.1 (A5), U9.1 (A5); also elsewhere on the board
/8086-processor/A7: U6.2 (A6), U7.2 (A6), U8.2 (A6), U9.2 (A6); also elsewhere on the board
/8086-processor/A8: U6.3 (A7), U7.3 (A7), U8.3 (A7), U9.3 (A7); also elsewhere on the board
/8086-processor/A9: U6.4 (A8), U7.4 (A8), U8.4 (A8), U9.4 (A8); also elsewhere on the board
/8086-processor/A10: U6.5 (A9), U7.5 (A9), U8.5 (A9), U9.5 (A9); also elsewhere on the board
/8086-processor/A11: U6.6 (A10), U7.6 (A10), U8.6 (A10), U9.6 (A10); also elsewhere on the board
/8086-processor/A12: U6.7 (A11), U7.7 (A11), U8.7 (A11), U9.7 (A11); also elsewhere on the board
/8086-processor/A13: U6.8 (A12), U7.8 (A12), U8.8 (A12), U9.8 (A12); also elsewhere on the board
/8086-processor/A14: U6.9 (A13), U7.9 (A13), U8.9 (A13), U9.9 (A13); also elsewhere on the board
/8086-processor/A15: U6.10 (A14), U7.10 (A14), U8.10 (A14), U9.10 (A14); also elsewhere on the board
/8086-processor/A16: U4.1 (A0), U5.1 (A0); also elsewhere on the board
/8086-processor/A17: U4.2 (A1), U5.2 (A1); also elsewhere on the board
/8086-processor/A18: U4.3 (A2), U5.3 (A2); also elsewhere on the board
/8086-processor/A19: U4.5 (E2), U5.5 (E2); also elsewhere on the board
/8086-processor/D0: U7.11 (D0), U9.11 (D0); also elsewhere on the board
/8086-processor/D1: U7.12 (D1), U9.12 (D1); also elsewhere on the board
/8086-processor/D2: U7.13 (D2), U9.13 (D2); also elsewhere on the board
/8086-processor/D3: U7.15 (D3), U9.15 (D3); also elsewhere on the board
/8086-processor/D4: U7.16 (D4), U9.16 (D4); also elsewhere on the board
/8086-processor/D5: U7.17 (D5), U9.17 (D5); also elsewhere on the board
/8086-processor/D6: U7.18 (D6), U9.18 (D6); also elsewhere on the board
/8086-processor/D7: U7.19 (D7), U9.19 (D7); also elsewhere on the board
/8086-processor/D8: U6.11 (D0), U8.11 (D0); also elsewhere on the board
/8086-processor/D9: U6.12 (D1), U8.12 (D1); also elsewhere on the board
/8086-processor/D10: U6.13 (D2), U8.13 (D2); also elsewhere on the board
/8086-processor/D11: U6.15 (D3), U8.15 (D3); also elsewhere on the board
/8086-processor/D12: U6.16 (D4), U8.16 (D4); also elsewhere on the board
/8086-processor/D13: U6.17 (D5), U8.17 (D5); also elsewhere on the board
/8086-processor/D14: U6.18 (D6), U8.18 (D6); also elsewhere on the board
/8086-processor/D15: U6.19 (D7), U8.19 (D7); also elsewhere on the board
/M\~IO: U4.6 (E3), U5.6 (E3); also elsewhere on the board
/SRAM/~CE_HI_0: U4.15 (O0), U6.20 (~CE~)
/SRAM/~CE_HI_1: U4.14 (O1), U8.20 (~CE~)
/SRAM/~CE_LO_0: U5.15 (O0), U7.20 (~CE~)
/SRAM/~CE_LO_1: U5.14 (O1), U9.20 (~CE~)
/~BHE: U4.4 (E1); also elsewhere on the board
/~RD: U6.22 (~OE~), U7.22 (~OE~), U8.22 (~OE~), U9.22 (~OE~); also elsewhere on the board
/~WR: U6.27 (~WE~), U7.27 (~WE~), U8.27 (~WE~), U9.27 (~WE~); also elsewhere on the board
GND: C7.2, C8.2, C9.2, C10.2, C11.2, C12.2, U4.8 (GND), U5.8 (GND), U6.14 (GND), U7.14 (GND), U8.14 (GND), U9.14 (GND); also elsewhere on the board
VCC: C7.1, C8.1, C9.1, C10.1, C11.1, C12.1, U4.16 (VCC), U5.16 (VCC), U6.28 (VCC), U7.28 (VCC), U8.28 (VCC), U9.28 (VCC); also elsewhere on the board

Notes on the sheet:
128kB SRAM Addresses 0x00000 to 0x1FFFF
Address decoding/chip select
Power decoupling
SRAM memory chips

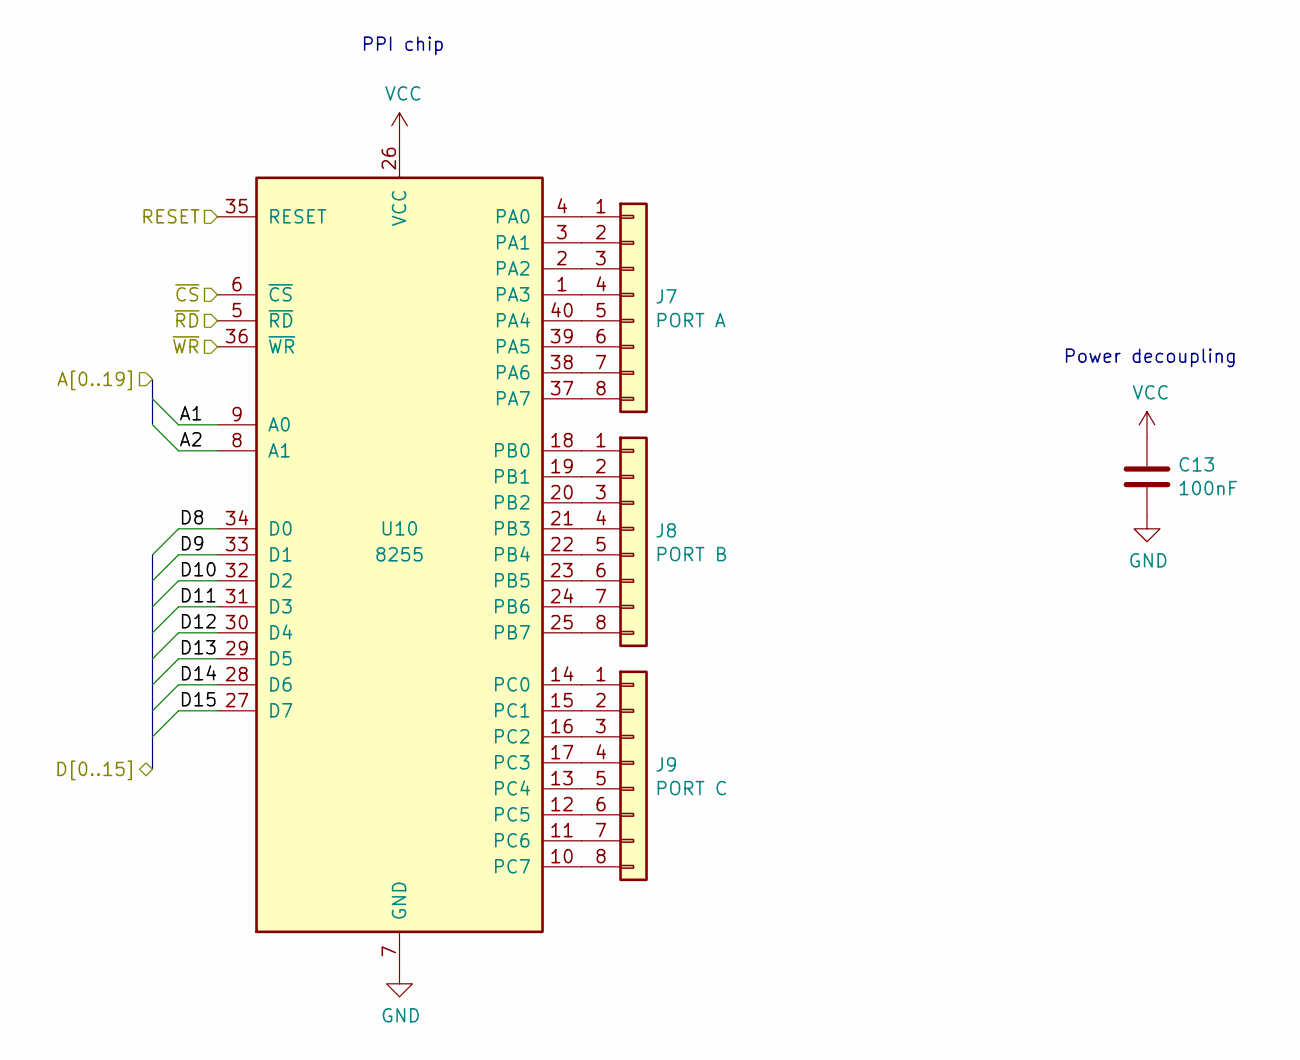
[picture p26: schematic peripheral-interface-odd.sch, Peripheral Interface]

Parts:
C13: 100nF; C_Rect_L4.0mm_W2.5mm_P2.50mm
J10: PORT A; PinHeader_1x08_P2.54mm_Vertical
J11: PORT B; PinHeader_1x08_P2.54mm_Vertical
J12: PORT C; PinHeader_1x08_P2.54mm_Vertical
U11: 8255; DIP-40_W15.24mm

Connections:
/8086-processor/A1: U11.9 (A0); also elsewhere on the board
/8086-processor/A2: U11.8 (A1); also elsewhere on the board
/8086-processor/D8: U11.34 (D0); also elsewhere on the board
/8086-processor/D9: U11.33 (D1); also elsewhere on the board
/8086-processor/D10: U11.32 (D2); also elsewhere on the board
/8086-processor/D11: U11.31 (D3); also elsewhere on the board
/8086-processor/D12: U11.30 (D4); also elsewhere on the board
/8086-processor/D13: U11.29 (D5); also elsewhere on the board
/8086-processor/D14: U11.28 (D6); also elsewhere on the board
/8086-processor/D15: U11.27 (D7); also elsewhere on the board
/RESET: U11.35 (RESET); also elsewhere on the board
/~CS_PPI1: U11.6 (~CS~); also elsewhere on the board
/~RD: U11.5 (~RD~); also elsewhere on the board
/~WR: U11.36 (~WR~); also elsewhere on the board
GND: C13.2, U11.7 (GND); also elsewhere on the board
unnamed: J10.1, U11.4 (PA0)
unnamed: J10.2, U11.3 (PA1)
unnamed: J10.3, U11.2 (PA2)
unnamed: J10.4, U11.1 (PA3)
unnamed: J10.5, U11.40 (PA4)
unnamed: J10.6, U11.39 (PA5)
unnamed: J10.7, U11.38 (PA6)
unnamed: J10.8, U11.37 (PA7)
unnamed: J11.1, U11.18 (PB0)
unnamed: J11.2, U11.19 (PB1)
unnamed: J11.3, U11.20 (PB2)
unnamed: J11.4, U11.21 (PB3)
unnamed: J11.5, U11.22 (PB4)
unnamed: J11.6, U11.23 (PB5)
unnamed: J11.7, U11.24 (PB6)
unnamed: J11.8, U11.25 (PB7)
unnamed: J12.1, U11.14 (PC0)
unnamed: J12.2, U11.15 (PC1)
unnamed: J12.3, U11.16 (PC2)
unnamed: J12.4, U11.17 (PC3)
unnamed: J12.5, U11.13 (PC4)
unnamed: J12.6, U11.12 (PC5)
unnamed: J12.7, U11.11 (PC6)
unnamed: J12.8, U11.10 (PC7)
VCC: C13.1, U11.26 (VCC); also elsewhere on the board

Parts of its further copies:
C14: 100nF; C_Rect_L4.0mm_W2.5mm_P2.50mm
J7: PORT A; PinHeader_1x08_P2.54mm_Vertical
J8: PORT B; PinHeader_1x08_P2.54mm_Vertical
J9: PORT C; PinHeader_1x08_P2.54mm_Vertical
U10: 8255; DIP-40_W15.24mm

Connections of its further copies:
/8086-processor/A1: U10.9 (A0); also elsewhere on the board
/8086-processor/A2: U10.8 (A1); also elsewhere on the board
/8086-processor/D8: U10.34 (D0); also elsewhere on the board
/8086-processor/D9: U10.33 (D1); also elsewhere on the board
/8086-processor/D10: U10.32 (D2); also elsewhere on the board
/8086-processor/D11: U10.31 (D3); also elsewhere on the board
/8086-processor/D12: U10.30 (D4); also elsewhere on the board
/8086-processor/D13: U10.29 (D5); also elsewhere on the board
/8086-processor/D14: U10.28 (D6); also elsewhere on the board
/8086-processor/D15: U10.27 (D7); also elsewhere on the board
/RESET: U10.35 (RESET); also elsewhere on the board
/~CS_PPI3: U10.6 (~CS~); also elsewhere on the board
/~RD: U10.5 (~RD~); also elsewhere on the board
/~WR: U10.36 (~WR~); also elsewhere on the board
GND: C14.2, U10.7 (GND); also elsewhere on the board
unnamed: J7.1, U10.4 (PA0)
unnamed: J7.2, U10.3 (PA1)
unnamed: J7.3, U10.2 (PA2)
unnamed: J7.4, U10.1 (PA3)
unnamed: J7.5, U10.40 (PA4)
unnamed: J7.6, U10.39 (PA5)
unnamed: J7.7, U10.38 (PA6)
unnamed: J7.8, U10.37 (PA7)
unnamed: J8.1, U10.18 (PB0)
unnamed: J8.2, U10.19 (PB1)
unnamed: J8.3, U10.20 (PB2)
unnamed: J8.4, U10.21 (PB3)
unnamed: J8.5, U10.22 (PB4)
unnamed: J8.6, U10.23 (PB5)
unnamed: J8.7, U10.24 (PB6)
unnamed: J8.8, U10.25 (PB7)
unnamed: J9.1, U10.14 (PC0)
unnamed: J9.2, U10.15 (PC1)
unnamed: J9.3, U10.16 (PC2)
unnamed: J9.4, U10.17 (PC3)
unnamed: J9.5, U10.13 (PC4)
unnamed: J9.6, U10.12 (PC5)
unnamed: J9.7, U10.11 (PC6)
unnamed: J9.8, U10.10 (PC7)
VCC: C14.1, U10.26 (VCC); also elsewhere on the board

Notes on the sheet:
PPI chip
Power decoupling

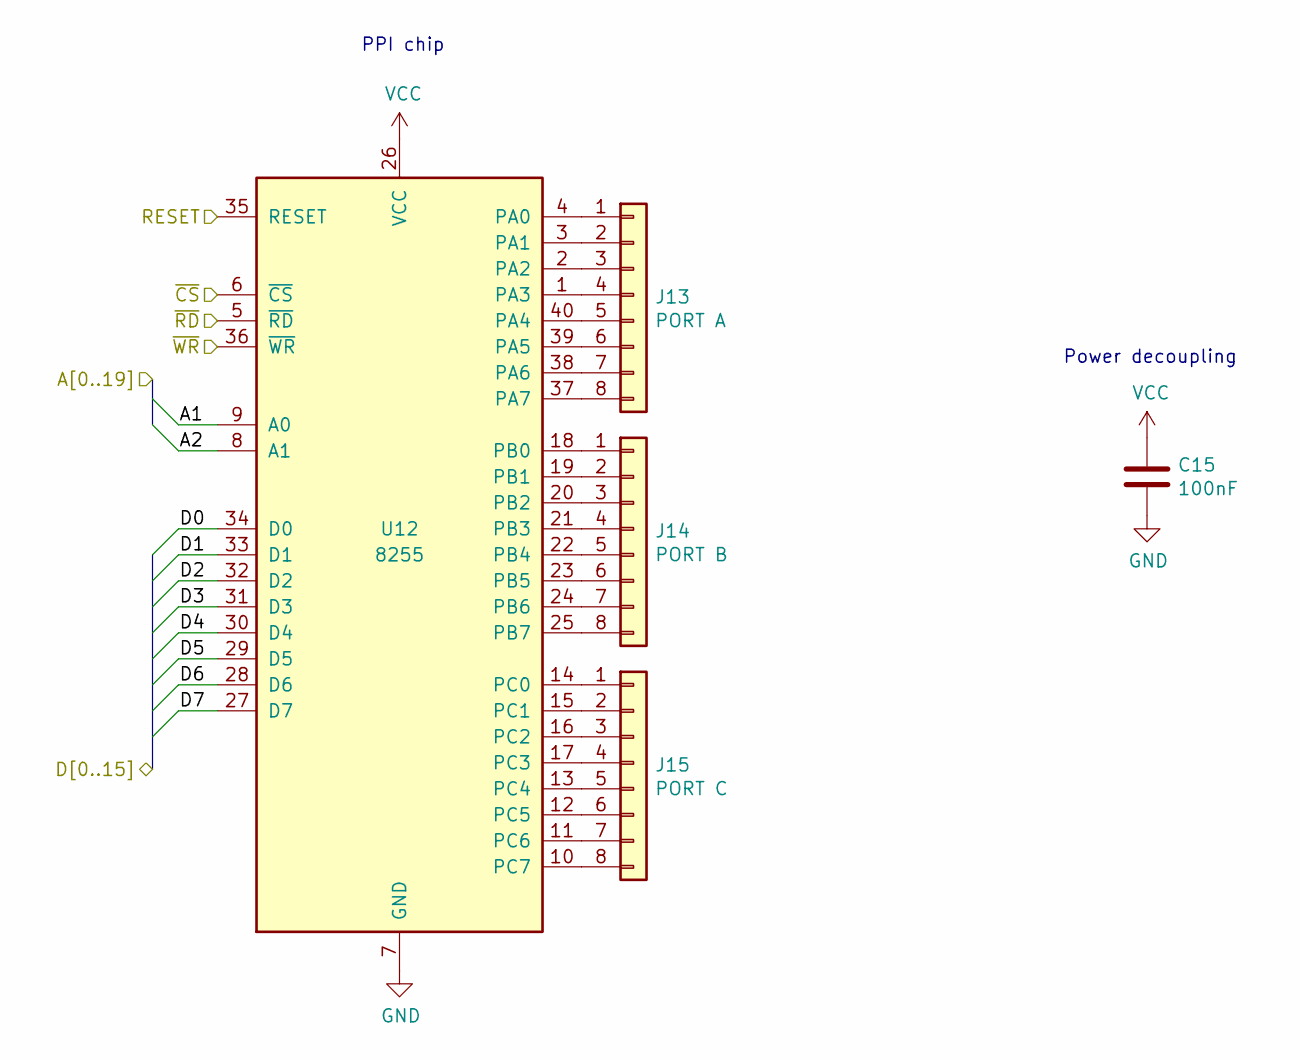
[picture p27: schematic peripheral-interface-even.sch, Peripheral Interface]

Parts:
C15: 100nF; C_Rect_L4.0mm_W2.5mm_P2.50mm
J13: PORT A; PinHeader_1x08_P2.54mm_Vertical
J14: PORT B; PinHeader_1x08_P2.54mm_Vertical
J15: PORT C; PinHeader_1x08_P2.54mm_Vertical
U12: 8255; DIP-40_W15.24mm

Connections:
/8086-processor/A1: U12.9 (A0); also elsewhere on the board
/8086-processor/A2: U12.8 (A1); also elsewhere on the board
/8086-processor/D0: U12.34 (D0); also elsewhere on the board
/8086-processor/D1: U12.33 (D1); also elsewhere on the board
/8086-processor/D2: U12.32 (D2); also elsewhere on the board
/8086-processor/D3: U12.31 (D3); also elsewhere on the board
/8086-processor/D4: U12.30 (D4); also elsewhere on the board
/8086-processor/D5: U12.29 (D5); also elsewhere on the board
/8086-processor/D6: U12.28 (D6); also elsewhere on the board
/8086-processor/D7: U12.27 (D7); also elsewhere on the board
/RESET: U12.35 (RESET); also elsewhere on the board
/~CS_PPI2: U12.6 (~CS~); also elsewhere on the board
/~RD: U12.5 (~RD~); also elsewhere on the board
/~WR: U12.36 (~WR~); also elsewhere on the board
GND: C15.2, U12.7 (GND); also elsewhere on the board
unnamed: J13.1, U12.4 (PA0)
unnamed: J13.2, U12.3 (PA1)
unnamed: J13.3, U12.2 (PA2)
unnamed: J13.4, U12.1 (PA3)
unnamed: J13.5, U12.40 (PA4)
unnamed: J13.6, U12.39 (PA5)
unnamed: J13.7, U12.38 (PA6)
unnamed: J13.8, U12.37 (PA7)
unnamed: J14.1, U12.18 (PB0)
unnamed: J14.2, U12.19 (PB1)
unnamed: J14.3, U12.20 (PB2)
unnamed: J14.4, U12.21 (PB3)
unnamed: J14.5, U12.22 (PB4)
unnamed: J14.6, U12.23 (PB5)
unnamed: J14.7, U12.24 (PB6)
unnamed: J14.8, U12.25 (PB7)
unnamed: J15.1, U12.14 (PC0)
unnamed: J15.2, U12.15 (PC1)
unnamed: J15.3, U12.16 (PC2)
unnamed: J15.4, U12.17 (PC3)
unnamed: J15.5, U12.13 (PC4)
unnamed: J15.6, U12.12 (PC5)
unnamed: J15.7, U12.11 (PC6)
unnamed: J15.8, U12.10 (PC7)
VCC: C15.1, U12.26 (VCC); also elsewhere on the board

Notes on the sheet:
PPI chip
Power decoupling

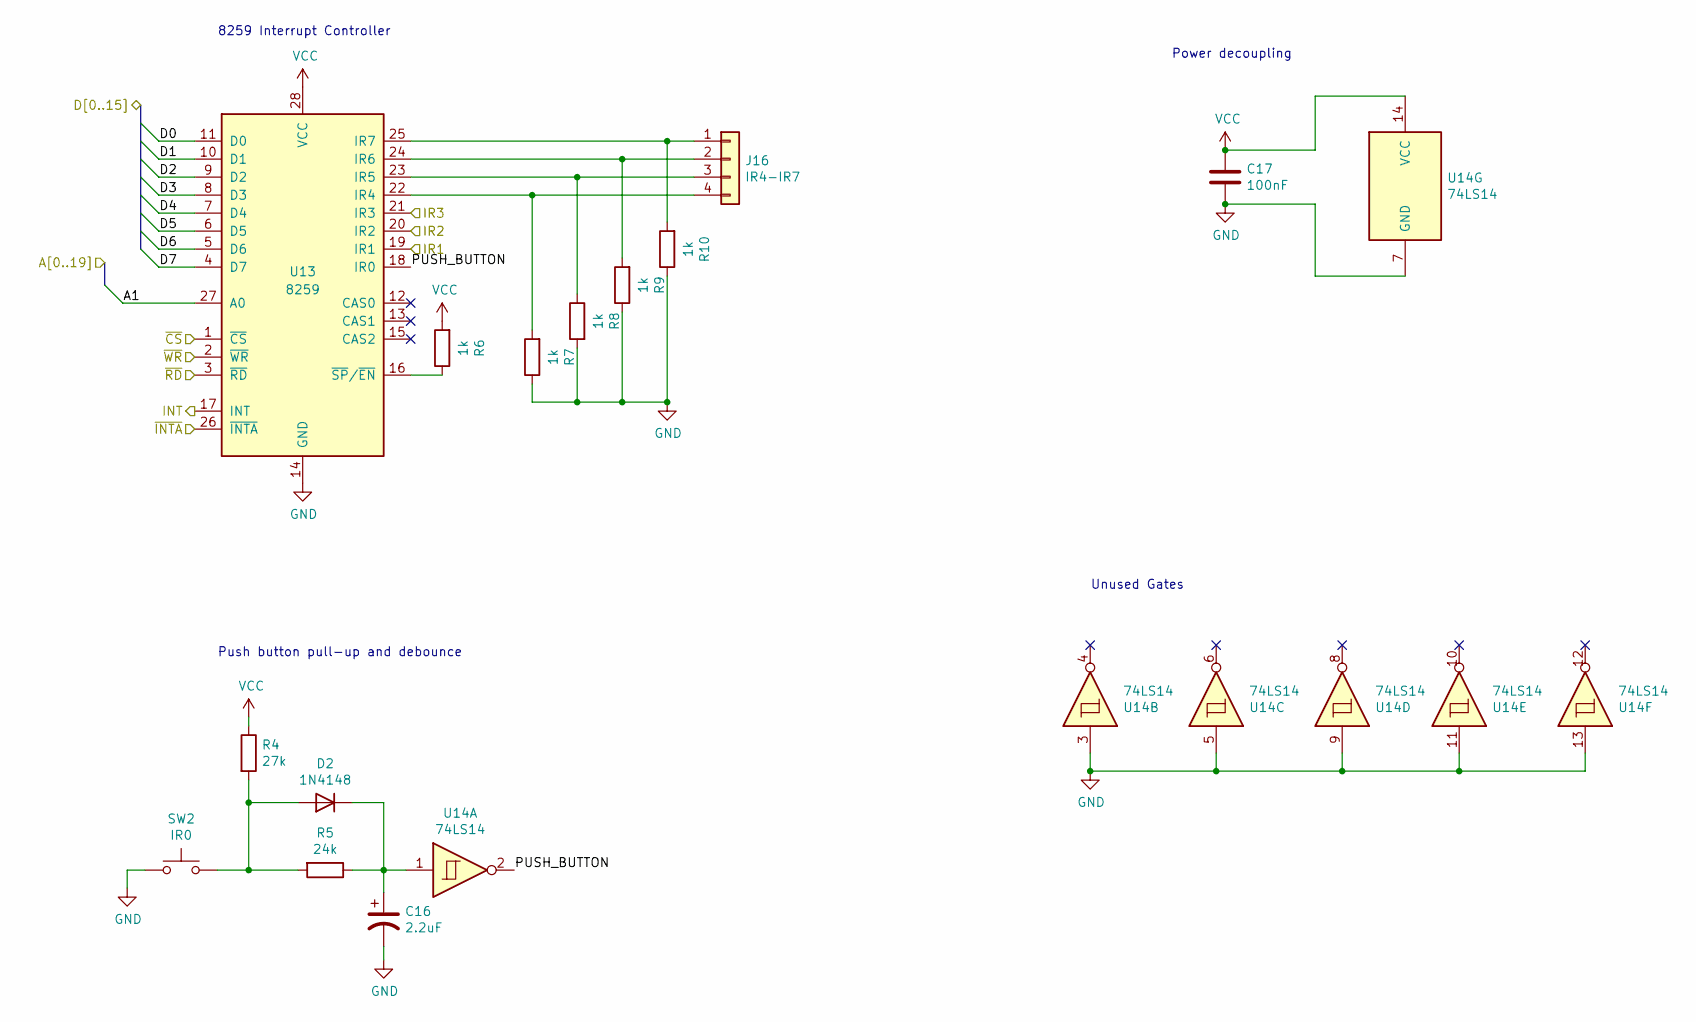
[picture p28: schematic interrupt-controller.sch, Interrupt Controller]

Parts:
C16: 2.2uF; CP_Radial_D5.0mm_P2.00mm
C17: 100nF; C_Rect_L4.0mm_W2.5mm_P2.50mm
D2: 1N4148; D_DO-35_SOD27_P7.62mm_Horizontal
J16: IR4-IR7; PinHeader_1x04_P2.54mm_Vertical
R4: 27k; R_Axial_DIN0207_L6.3mm_D2.5mm_P10.16mm_Horizontal
R5: 24k; R_Axial_DIN0207_L6.3mm_D2.5mm_P10.16mm_Horizontal
R6, R7, R8, R9, R10: 1k; R_Axial_DIN0207_L6.3mm_D2.5mm_P10.16mm_Horizontal
SW2: IR0; SW_Cherry_MX_1.00u_PCB
U13: 8259; DIP-28_W15.24mm
U14: 74LS14; DIP-14_W7.62mm

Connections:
/8086-processor/A1: U13.27 (A0); also elsewhere on the board
/8086-processor/D0: U13.11 (D0); also elsewhere on the board
/8086-processor/D1: U13.10 (D1); also elsewhere on the board
/8086-processor/D2: U13.9 (D2); also elsewhere on the board
/8086-processor/D3: U13.8 (D3); also elsewhere on the board
/8086-processor/D4: U13.7 (D4); also elsewhere on the board
/8086-processor/D5: U13.6 (D5); also elsewhere on the board
/8086-processor/D6: U13.5 (D6); also elsewhere on the board
/8086-processor/D7: U13.4 (D7); also elsewhere on the board
/COUNTER_INTR: U13.19 (IR1); also elsewhere on the board
/INTR: U13.17 (INT); also elsewhere on the board
/KEYBOARD_INTR: U13.20 (IR2); also elsewhere on the board
/UART_INTR: U13.21 (IR3); also elsewhere on the board
/interrupt-controller/PUSH_BUTTON: U13.18 (IR0), U14.2
/~CS_INTR: U13.1 (~CS~); also elsewhere on the board
/~INTA: U13.26 (~INTA~); also elsewhere on the board
/~RD: U13.3 (~RD~); also elsewhere on the board
/~WR: U13.2 (~WR~); also elsewhere on the board
GND: C16.2, C17.2, R7.1, R8.2, R9.1, R10.1, SW2.1, U13.14 (GND), U14.3, U14.5, U14.7 (GND), U14.9, U14.11, U14.13; also elsewhere on the board
unnamed: C16.1, D2.1 (K), R5.1, U14.1
unnamed: D2.2 (A), R4.2, R5.2, SW2.2
unnamed: J16.1, R10.2, U13.25 (IR7)
unnamed: J16.2, R9.2, U13.24 (IR6)
unnamed: J16.3, R8.1, U13.23 (IR5)
unnamed: J16.4, R7.2, U13.22 (IR4)
unnamed: R6.1, U13.16 (~SP~/~EN~)
VCC: C17.1, R4.1, R6.2, U13.28 (VCC), U14.14 (VCC); also elsewhere on the board

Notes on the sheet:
Power decoupling
8259 Interrupt Controller
Push button pull-up and debounce
Unused Gates

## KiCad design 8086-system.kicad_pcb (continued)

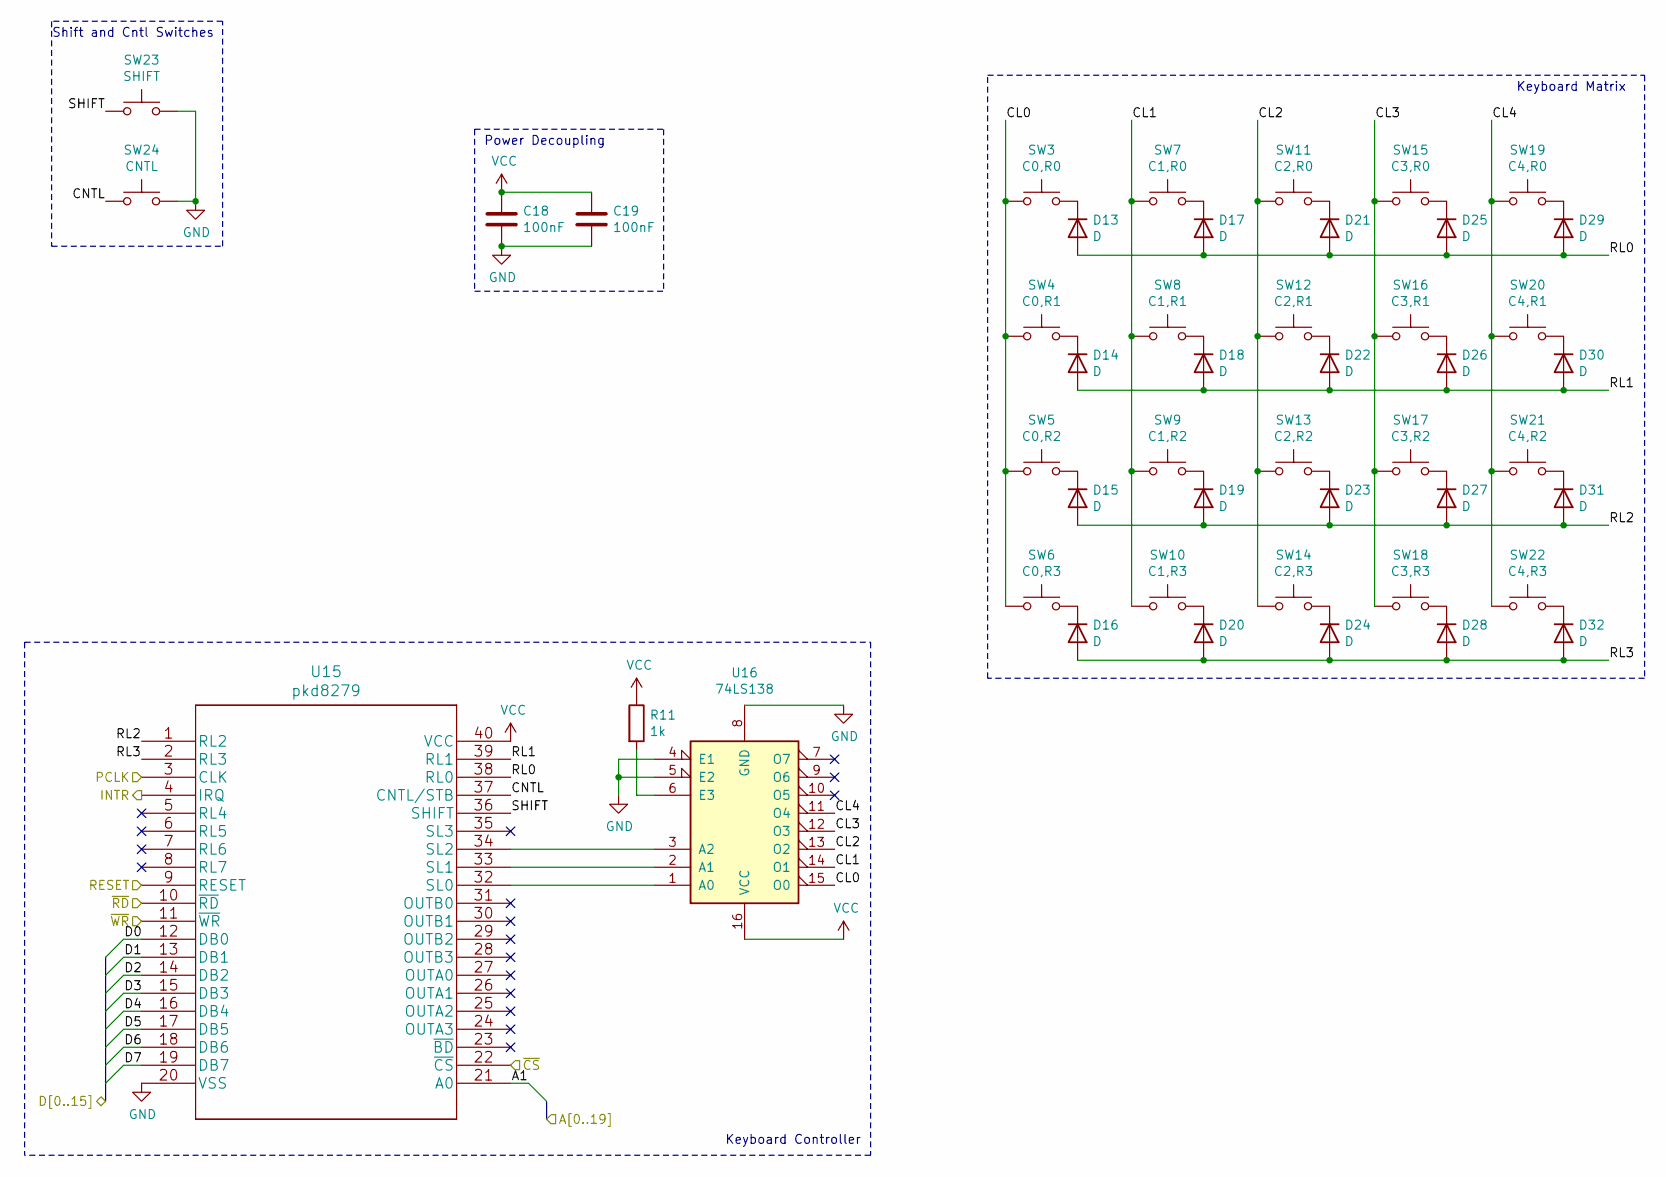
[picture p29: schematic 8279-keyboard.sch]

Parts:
C18, C19: 100nF; C_Rect_L4.0mm_W2.5mm_P2.50mm
D13, D14, D15, D16, D17, D18, D19, D20, D21, D22, D23, D24, D25, D26, D27, D28, D29, D30, D31, D32: D; D_DO-35_SOD27_P7.62mm_Horizontal
R11: 1k; R_Axial_DIN0207_L6.3mm_D2.5mm_P10.16mm_Horizontal
SW3: C0,R0; SW_Cherry_MX_1.00u_PCB
SW4: C0,R1; SW_Cherry_MX_1.00u_PCB
SW5: C0,R2; SW_Cherry_MX_1.00u_PCB
SW6: C0,R3; SW_Cherry_MX_1.00u_PCB
SW7: C1,R0; SW_Cherry_MX_1.00u_PCB
SW8: C1,R1; SW_Cherry_MX_1.00u_PCB
SW9: C1,R2; SW_Cherry_MX_1.00u_PCB
SW10: C1,R3; SW_Cherry_MX_1.00u_PCB
SW11: C2,R0; SW_Cherry_MX_1.00u_PCB
SW12: C2,R1; SW_Cherry_MX_1.00u_PCB
SW13: C2,R2; SW_Cherry_MX_1.00u_PCB
SW14: C2,R3; SW_Cherry_MX_1.00u_PCB
SW15: C3,R0; SW_Cherry_MX_1.00u_PCB
SW16: C3,R1; SW_Cherry_MX_1.00u_PCB
SW17: C3,R2; SW_Cherry_MX_1.00u_PCB
SW18: C3,R3; SW_Cherry_MX_1.00u_PCB
SW19: C4,R0; SW_Cherry_MX_1.00u_PCB
SW20: C4,R1; SW_Cherry_MX_1.00u_PCB
SW21: C4,R2; SW_Cherry_MX_1.00u_PCB
SW22: C4,R3; SW_Cherry_MX_1.00u_PCB
SW23: SHIFT; SW_Cherry_MX_1.00u_PCB
SW24: CNTL; SW_Cherry_MX_1.00u_PCB
U15: pkd8279
U16: 74LS138; DIP-16_W7.62mm

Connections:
/8086-processor/A1: U15.21 (A0); also elsewhere on the board
/8086-processor/D0: U15.12 (DB0); also elsewhere on the board
/8086-processor/D1: U15.13 (DB1); also elsewhere on the board
/8086-processor/D2: U15.14 (DB2); also elsewhere on the board
/8086-processor/D3: U15.15 (DB3); also elsewhere on the board
/8086-processor/D4: U15.16 (DB4); also elsewhere on the board
/8086-processor/D5: U15.17 (DB5); also elsewhere on the board
/8086-processor/D6: U15.18 (DB6); also elsewhere on the board
/8086-processor/D7: U15.19 (DB7); also elsewhere on the board
/8279-keyboard/CL0: SW3.1, SW4.1, SW5.1, SW6.1, U16.15 (O0)
/8279-keyboard/CL1: SW7.1, SW8.1, SW9.1, SW10.1, U16.14 (O1)
/8279-keyboard/CL2: SW11.1, SW12.1, SW13.1, SW14.1, U16.13 (O2)
/8279-keyboard/CL3: SW15.1, SW16.1, SW17.1, SW18.1, U16.12 (O3)
/8279-keyboard/CL4: SW19.1, SW20.1, SW21.1, SW22.1, U16.11 (O4)
/8279-keyboard/CNTL: SW24.1, U15.37 (CNTL/STB)
/8279-keyboard/RL0: D13.2 (A), D17.2 (A), D21.2 (A), D25.2 (A), D29.2 (A), U15.38 (RL0)
/8279-keyboard/RL1: D14.2 (A), D18.2 (A), D22.2 (A), D26.2 (A), D30.2 (A), U15.39 (RL1)
/8279-keyboard/RL2: D15.2 (A), D19.2 (A), D23.2 (A), D27.2 (A), D31.2 (A), U15.1 (RL2)
/8279-keyboard/RL3: D16.2 (A), D20.2 (A), D24.2 (A), D28.2 (A), D32.2 (A), U15.2 (RL3)
/8279-keyboard/SHIFT: SW23.1, U15.36 (SHIFT)
/KEYBOARD_INTR: U15.4 (IRQ); also elsewhere on the board
/PCLK: U15.3 (CLK); also elsewhere on the board
/RESET: U15.9 (RESET); also elsewhere on the board
/~CS_KEYBOARD: U15.22 (~CS); also elsewhere on the board
/~RD: U15.10 (~RD); also elsewhere on the board
/~WR: U15.11 (~WR); also elsewhere on the board
GND: C18.2, C19.2, SW23.2, SW24.2, U15.20 (VSS), U16.4 (E1), U16.5 (E2), U16.8 (GND); also elsewhere on the board
unnamed: D13.1 (K), SW3.2
unnamed: D14.1 (K), SW4.2
unnamed: D15.1 (K), SW5.2
unnamed: D16.1 (K), SW6.2
unnamed: D17.1 (K), SW7.2
unnamed: D18.1 (K), SW8.2
unnamed: D19.1 (K), SW9.2
unnamed: D20.1 (K), SW10.2
unnamed: D21.1 (K), SW11.2
unnamed: D22.1 (K), SW12.2
unnamed: D23.1 (K), SW13.2
unnamed: D24.1 (K), SW14.2
unnamed: D25.1 (K), SW15.2
unnamed: D26.1 (K), SW16.2
unnamed: D27.1 (K), SW17.2
unnamed: D28.1 (K), SW18.2
unnamed: D29.1 (K), SW19.2
unnamed: D30.1 (K), SW20.2
unnamed: D31.1 (K), SW21.2
unnamed: D32.1 (K), SW22.2
unnamed: R11.2, U16.6 (E3)
unnamed: U15.32 (SL0), U16.1 (A0)
unnamed: U15.33 (SL1), U16.2 (A1)
unnamed: U15.34 (SL2), U16.3 (A2)
VCC: C18.1, C19.1, R11.1, U15.40 (VCC), U16.16 (VCC); also elsewhere on the board

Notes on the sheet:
Keyboard Matrix
Keyboard Controller
Shift and Cntl Switches
Power Decoupling

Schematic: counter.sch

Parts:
C20: 100nF; C_Rect_L4.0mm_W2.5mm_P2.50mm
J17: Counter0; PinHeader_1x03_P2.54mm_Vertical
J18: Counter1; PinHeader_1x03_P2.54mm_Vertical
J19: Counter2; PinHeader_1x03_P2.54mm_Vertical
R12, R13, R14, R15, R16, R17: 1k; R_Axial_DIN0207_L6.3mm_D2.5mm_P10.16mm_Horizontal
U17: 8254; DIP-24_W15.24mm

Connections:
/8086-processor/A1: U17.19 (A0); also elsewhere on the board
/8086-processor/A2: U17.20 (A1); also elsewhere on the board
/8086-processor/D0: U17.8 (D0); also elsewhere on the board
/8086-processor/D1: U17.7 (D1); also elsewhere on the board
/8086-processor/D2: U17.6 (D2); also elsewhere on the board
/8086-processor/D3: U17.5 (D3); also elsewhere on the board
/8086-processor/D4: U17.4 (D4); also elsewhere on the board
/8086-processor/D5: U17.3 (D5); also elsewhere on the board
/8086-processor/D6: U17.2 (D6); also elsewhere on the board
/8086-processor/D7: U17.1 (D7); also elsewhere on the board
/COUNTER_INTR: U17.13 (OUT1); also elsewhere on the board
/~CS_COUNTER: U17.21 (~CS~); also elsewhere on the board
/~RD: U17.22 (~RD~); also elsewhere on the board
/~WR: U17.23 (~WR~); also elsewhere on the board
GND: C20.2, J18.3, R12.2, R13.2, R14.2, R15.2, R16.2, R17.2, U17.12 (GND); also elsewhere on the board
unnamed: J17.1, R12.1, U17.9 (CLK0)
unnamed: J17.2, R13.1, U17.11 (G0)
unnamed: J17.3, U17.10 (OUT0)
unnamed: J18.1, R14.1, U17.15 (CLK1)
unnamed: J18.2, R15.1, U17.14 (G1)
unnamed: J19.1, R16.1, U17.18 (CLK2)
unnamed: J19.2, R17.1, U17.16 (G2)
unnamed: J19.3, U17.17 (OUT2)
VCC: C20.1, U17.24 (VCC); also elsewhere on the board

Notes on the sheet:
8254 Interval Timer
Power decoupling

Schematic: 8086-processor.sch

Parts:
C21, C22, C23, C24, C25, C26, C27, C28: 100nF; C_Rect_L4.0mm_W2.5mm_P2.50mm
D3: 1N4148; D_DO-35_SOD27_P7.62mm_Horizontal
R18, R20: 1k; R_Axial_DIN0207_L6.3mm_D2.5mm_P10.16mm_Horizontal
R19: 10k; R_Axial_DIN0207_L6.3mm_D2.5mm_P10.16mm_Horizontal
SW25: NMI; SW_Cherry_MX_1.00u_PCB
U18: 8086_Min_Mode; DIP-40_W15.24mm
U19, U21, U22: 74LS374; DIP-20_W7.62mm
U20: 74LS244; DIP-20_W7.62mm
U23, U24: 74LS245; DIP-20_W7.62mm

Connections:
/8086-processor/A0: U19.9 (O3); also elsewhere on the board
/8086-processor/A1: U19.6 (O2); also elsewhere on the board
/8086-processor/A2: U19.5 (O1); also elsewhere on the board
/8086-processor/A3: U19.2 (O0); also elsewhere on the board
/8086-processor/A4: U19.12 (O4); also elsewhere on the board
/8086-processor/A5: U19.15 (O5); also elsewhere on the board
/8086-processor/A6: U19.16 (O6); also elsewhere on the board
/8086-processor/A7: U19.19 (O7); also elsewhere on the board
/8086-processor/A8: U21.9 (O3); also elsewhere on the board
/8086-processor/A9: U21.6 (O2); also elsewhere on the board
/8086-processor/A10: U21.5 (O1); also elsewhere on the board
/8086-processor/A11: U21.2 (O0); also elsewhere on the board
/8086-processor/A12: U21.12 (O4); also elsewhere on the board
/8086-processor/A13: U21.15 (O5); also elsewhere on the board
/8086-processor/A14: U21.16 (O6); also elsewhere on the board
/8086-processor/A15: U21.19 (O7); also elsewhere on the board
/8086-processor/A16: U22.2 (O0); also elsewhere on the board
/8086-processor/A17: U22.5 (O1); also elsewhere on the board
/8086-processor/A18: U22.6 (O2); also elsewhere on the board
/8086-processor/A19: U22.9 (O3); also elsewhere on the board
/8086-processor/ALE: U18.25 (ALE), U19.11 (Cp), U21.11 (Cp), U22.11 (Cp)
/8086-processor/D0: U23.18 (B0); also elsewhere on the board
/8086-processor/D1: U23.17 (B1); also elsewhere on the board
/8086-processor/D2: U23.16 (B2); also elsewhere on the board
/8086-processor/D3: U23.15 (B3); also elsewhere on the board
/8086-processor/D4: U23.14 (B4); also elsewhere on the board
/8086-processor/D5: U23.13 (B5); also elsewhere on the board
/8086-processor/D6: U23.12 (B6); also elsewhere on the board
/8086-processor/D7: U23.11 (B7); also elsewhere on the board
/8086-processor/D8: U24.18 (B0); also elsewhere on the board
/8086-processor/D9: U24.17 (B1); also elsewhere on the board
/8086-processor/D10: U24.16 (B2); also elsewhere on the board
/8086-processor/D11: U24.15 (B3); also elsewhere on the board
/8086-processor/D12: U24.14 (B4); also elsewhere on the board
/8086-processor/D13: U24.13 (B5); also elsewhere on the board
/8086-processor/D14: U24.12 (B6); also elsewhere on the board
/8086-processor/D15: U24.11 (B7); also elsewhere on the board
/8086-processor/DT\~R: U18.27 (DT/~R~), U23.1 (A->B), U24.1 (A->B)
/8086-processor/NMI: U18.17 (NMI), U20.12 (O3a)
/8086-processor/~DEN: U18.26 (~DEN~), U23.19 (CE), U24.19 (CE)
/CLK: U18.19 (CLK); also elsewhere on the board
/INTR: U18.18 (INTR); also elsewhere on the board
/M\~IO: U20.18 (O0a); also elsewhere on the board
/READY: U18.22 (READY); also elsewhere on the board
/RESET: U18.21 (RESET); also elsewhere on the board
/~BHE: U22.12 (O4); also elsewhere on the board
/~INTA: U18.24 (~INTA~); also elsewhere on the board
/~RD: U20.14 (O2a); also elsewhere on the board
/~WR: U20.16 (O1a); also elsewhere on the board
GND: C22.1, C23.1, C24.1, C25.1, C26.1, C27.1, C28.1, R19.1, U18.1 (GND), U18.20 (GND), U18.23 (~TEST~), U18.31 (HOLD), U19.1 (OE), U19.10 (GND), U20.1 (OEa), U20.10 (GND), U20.11 (I0b), U20.13 (I1b), U20.15 (I2b), U20.17 (I3b), U20.19 (OEb), U21.1 (OE), U21.10 (GND), U22.1 (OE), U22.10 (GND), U22.14 (D5), U22.17 (D6), U22.18 (D7), U23.10 (GND), U24.10 (GND); also elsewhere on the board
unnamed: C21.2, D3.2 (A), R20.1, U20.8 (I3a)
unnamed: D3.1 (K), R19.2, R20.2, SW25.1
unnamed: R18.2, U18.33 (MN/~MX~)
unnamed: U18.2 (AD14), U21.17 (D6), U24.8 (A6)
unnamed: U18.3 (AD13), U21.14 (D5), U24.7 (A5)
unnamed: U18.4 (AD12), U21.13 (D4), U24.6 (A4)
unnamed: U18.5 (AD11), U21.3 (D0), U24.5 (A3)
unnamed: U18.6 (AD10), U21.4 (D1), U24.4 (A2)
unnamed: U18.7 (AD9), U21.7 (D2), U24.3 (A1)
unnamed: U18.8 (AD8), U21.8 (D3), U24.2 (A0)
unnamed: U18.9 (AD7), U19.18 (D7), U23.9 (A7)
unnamed: U18.10 (AD6), U19.17 (D6), U23.8 (A6)
unnamed: U18.11 (AD5), U19.14 (D5), U23.7 (A5)
unnamed: U18.12 (AD4), U19.13 (D4), U23.6 (A4)
unnamed: U18.13 (AD3), U19.3 (D0), U23.5 (A3)
unnamed: U18.14 (AD2), U19.4 (D1), U23.4 (A2)
unnamed: U18.15 (AD1), U19.7 (D2), U23.3 (A1)
unnamed: U18.16 (AD0), U19.8 (D3), U23.2 (A0)
unnamed: U18.28 (M/~IO~), U20.2 (I0a)
unnamed: U18.29 (~WR~), U20.4 (I1a)
unnamed: U18.32 (~RD~), U20.6 (I2a)
unnamed: U18.34 (~BHE~/S7), U22.13 (D4)
unnamed: U18.35 (A19/S6), U22.8 (D3)
unnamed: U18.36 (A18/S5), U22.7 (D2)
unnamed: U18.37 (A17/S4), U22.4 (D1)
unnamed: U18.38 (A16/S3), U22.3 (D0)
unnamed: U18.39 (AD15), U21.18 (D7), U24.9 (A7)
VCC: C21.1, C22.2, C23.2, C24.2, C25.2, C26.2, C27.2, C28.2, R18.1, SW25.2, U18.40 (VCC), U19.20 (VCC), U20.20 (VCC), U21.20 (VCC), U22.20 (VCC), U23.20 (VCC), U24.20 (VCC); also elsewhere on the board

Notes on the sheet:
Data Bus Transceivers
Address Bus Latches
8086 Processor
Power Decoupling
Non-Maskable Interrupt Button

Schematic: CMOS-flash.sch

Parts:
C29, C30, C31, C32, C33, C34: 100nF; C_Rect_L4.0mm_W2.5mm_P2.50mm
U25, U26: 74LS138; DIP-16_W7.62mm
U27, U28: 28F010

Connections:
+12V: C29.1, C30.1, U27.1 (VPP), U28.1 (VPP); also elsewhere on the board
/8086-processor/A0: U26.5 (E2); also elsewhere on the board
/8086-processor/A1: U27.12 (A0), U28.12 (A0); also elsewhere on the board
/8086-processor/A2: U27.11 (A1), U28.11 (A1); also elsewhere on the board
/8086-processor/A3: U27.10 (A2), U28.10 (A2); also elsewhere on the board
/8086-processor/A4: U27.9 (A3), U28.9 (A3); also elsewhere on the board
/8086-processor/A5: U27.8 (A4), U28.8 (A4); also elsewhere on the board
/8086-processor/A6: U27.7 (A5), U28.7 (A5); also elsewhere on the board
/8086-processor/A7: U27.6 (A6), U28.6 (A6); also elsewhere on the board
/8086-processor/A8: U27.5 (A7), U28.5 (A7); also elsewhere on the board
/8086-processor/A9: U27.27 (A8), U28.27 (A8); also elsewhere on the board
/8086-processor/A10: U27.26 (A9), U28.26 (A9); also elsewhere on the board
/8086-processor/A11: U27.23 (A10), U28.23 (A10); also elsewhere on the board
/8086-processor/A12: U27.25 (A11), U28.25 (A11); also elsewhere on the board
/8086-processor/A13: U27.4 (A12), U28.4 (A12); also elsewhere on the board
/8086-processor/A14: U27.28 (A13), U28.28 (A13); also elsewhere on the board
/8086-processor/A15: U27.29 (A14), U28.29 (A14); also elsewhere on the board
/8086-processor/A16: U27.3 (A15), U28.3 (A15); also elsewhere on the board
/8086-processor/A17: U27.2 (A16), U28.2 (A16); also elsewhere on the board
/8086-processor/A18: U25.1 (A0), U26.1 (A0); also elsewhere on the board
/8086-processor/A19: U25.2 (A1), U26.2 (A1); also elsewhere on the board
/8086-processor/D0: U28.13 (DQ0); also elsewhere on the board
/8086-processor/D1: U28.14 (DQ1); also elsewhere on the board
/8086-processor/D2: U28.15 (DQ2); also elsewhere on the board
/8086-processor/D3: U28.17 (DQ3); also elsewhere on the board
/8086-processor/D4: U28.18 (DQ4); also elsewhere on the board
/8086-processor/D5: U28.19 (DQ5); also elsewhere on the board
/8086-processor/D6: U28.20 (DQ6); also elsewhere on the board
/8086-processor/D7: U28.21 (DQ7); also elsewhere on the board
/8086-processor/D8: U27.13 (DQ0); also elsewhere on the board
/8086-processor/D9: U27.14 (DQ1); also elsewhere on the board
/8086-processor/D10: U27.15 (DQ2); also elsewhere on the board
/8086-processor/D11: U27.17 (DQ3); also elsewhere on the board
/8086-processor/D12: U27.18 (DQ4); also elsewhere on the board
/8086-processor/D13: U27.19 (DQ5); also elsewhere on the board
/8086-processor/D14: U27.20 (DQ6); also elsewhere on the board
/8086-processor/D15: U27.21 (DQ7); also elsewhere on the board
/CMOS-flash/~CE_HI_BYTE: U25.12 (O3), U27.22 (CE)
/CMOS-flash/~CE_LOW_BYTE: U26.12 (O3), U28.22 (CE)
/M\~IO: U25.6 (E3), U26.6 (E3); also elsewhere on the board
/~BHE: U25.5 (E2); also elsewhere on the board
/~RD: U27.24 (OE), U28.24 (OE); also elsewhere on the board
/~WR: U27.31 (WE), U28.31 (WE); also elsewhere on the board
GND: C29.2, C30.2, C31.2, C32.2, C33.2, C34.2, U25.3 (A2), U25.4 (E1), U25.8 (GND), U26.3 (A2), U26.4 (E1), U26.8 (GND), U27.16 (VSS), U28.16 (VSS); also elsewhere on the board
VCC: C31.1, C32.1, C33.1, C34.1, U25.16 (VCC), U26.16 (VCC), U27.32 (VCC), U28.32 (VCC); also elsewhere on the board

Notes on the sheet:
256kB CMOS Flash Addresses 0xC0000 to 0xFFFFF
Address Decoding
Power Decoupling
Flash Memory Chips

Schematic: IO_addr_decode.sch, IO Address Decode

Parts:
C35, C36: 100nF; C_Rect_L4.0mm_W2.5mm_P2.50mm
U29: 74LS30; DIP-14_W7.62mm
U30, U31: PAL16L8; DIP-20_W7.62mm

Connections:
/8086-processor/A0: U30.1 (I1), U31.1 (I1); also elsewhere on the board
/8086-processor/A1: U30.2 (I2), U31.2 (I2); also elsewhere on the board
/8086-processor/A2: U30.3 (I3), U31.3 (I3); also elsewhere on the board
/8086-processor/A3: U30.4 (I4), U31.4 (I4); also elsewhere on the board
/8086-processor/A4: U30.5 (I5), U31.5 (I5); also elsewhere on the board
/8086-processor/A5: U30.6 (I6), U31.6 (I6); also elsewhere on the board
/8086-processor/A6: U30.7 (I7), U31.7 (I7); also elsewhere on the board
/8086-processor/A7: U30.8 (I8), U31.8 (I8); also elsewhere on the board
/8086-processor/A8: U29.1; also elsewhere on the board
/8086-processor/A9: U29.2; also elsewhere on the board
/8086-processor/A10: U29.3; also elsewhere on the board
/8086-processor/A11: U29.4; also elsewhere on the board
/8086-processor/A12: U29.5; also elsewhere on the board
/8086-processor/A13: U29.6; also elsewhere on the board
/8086-processor/A14: U29.11; also elsewhere on the board
/8086-processor/A15: U29.12; also elsewhere on the board
/IO_addr_decode/~HI_BYTE_FF: U29.8, U30.9 (I9), U31.9 (I9)
/M\~IO: U30.11 (I10), U31.11 (I10); also elsewhere on the board
/~BHE: U30.12 (IO8), U31.12 (IO8); also elsewhere on the board
/~CS_COUNTER: U30.15 (IO5); also elsewhere on the board
/~CS_INTR: U30.16 (IO4); also elsewhere on the board
/~CS_KEYBOARD: U30.14 (IO6); also elsewhere on the board
/~CS_PPI1: U30.18 (IO2); also elsewhere on the board
/~CS_PPI2: U30.19 (IO1); also elsewhere on the board
/~CS_PPI3: U30.17 (I03); also elsewhere on the board
/~CS_UART: U31.14 (IO6); also elsewhere on the board
/~DIP_CS: U31.16 (IO4); also elsewhere on the board
/~EVEN_7_SEG_CS: U31.18 (IO2); also elsewhere on the board
/~LCD_CS: U31.15 (IO5); also elsewhere on the board
/~LED_CS: U31.19 (IO1); also elsewhere on the board
/~ODD_7_SEG_CS: U31.17 (I03); also elsewhere on the board
GND: C35.2, C36.2, U29.7 (GND), U30.10 (GND), U31.10 (GND); also elsewhere on the board
VCC: C35.1, C36.1, U29.14 (VCC), U30.20 (VCC), U31.20 (VCC); also elsewhere on the board

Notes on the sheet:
Decode high byte
Power decoupling
16L8 PAL: decode low byte

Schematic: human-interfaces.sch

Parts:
C37, C38, C39, C40, C41: 100nF; C_Rect_L4.0mm_W2.5mm_P2.50mm
D4, D5, D6, D7, D8, D9, D10, D11: LED; LED_D5.0mm
DS1: LCD4x20; Mouser Part Number 763-0420AZFLYBW33V3
R21, R22: R; R_Axial_DIN0207_L6.3mm_D2.5mm_P10.16mm_Horizontal
RN1, RN2: R_Pack08; DIP-16_W7.62mm
SW26: SW_DIP_x08; DIP-16_W7.62mm
U32: 74LS02; DIP-20_W7.62mm
U33: 74LS32; DIP-20_W7.62mm
U34, U36, U38: 74LS374; DIP-20_W7.62mm
U37, U40: HDSP-A153; HDSP-A151
U39: 74LS244; DIP-20_W7.62mm

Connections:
/8086-processor/A1: DS1.5 (R/W); also elsewhere on the board
/8086-processor/A2: DS1.4 (RS); also elsewhere on the board
/8086-processor/D0: DS1.7 (DB0), U34.3 (D0), U36.3 (D0), U39.18 (O0a); also elsewhere on the board
/8086-processor/D1: DS1.8 (DB1), U34.4 (D1), U36.4 (D1), U39.16 (O1a); also elsewhere on the board
/8086-processor/D2: DS1.9 (DB2), U34.7 (D2), U36.7 (D2), U39.14 (O2a); also elsewhere on the board
/8086-processor/D3: DS1.10 (DB3), U34.8 (D3), U36.8 (D3), U39.12 (O3a); also elsewhere on the board
/8086-processor/D4: DS1.11 (DB4), U34.13 (D4), U36.13 (D4), U39.9 (O0b); also elsewhere on the board
/8086-processor/D5: DS1.12 (DB5), U34.14 (D5), U36.14 (D5), U39.7 (O1b); also elsewhere on the board
/8086-processor/D6: DS1.13 (DB6), U34.17 (D6), U36.17 (D6), U39.5 (O2b); also elsewhere on the board
/8086-processor/D7: DS1.14 (DB7), U34.18 (D7), U36.18 (D7), U39.3 (O3b); also elsewhere on the board
/8086-processor/D8: U38.3 (D0); also elsewhere on the board
/8086-processor/D9: U38.4 (D1); also elsewhere on the board
/8086-processor/D10: U38.7 (D2); also elsewhere on the board
/8086-processor/D11: U38.8 (D3); also elsewhere on the board
/8086-processor/D12: U38.13 (D4); also elsewhere on the board
/8086-processor/D13: U38.14 (D5); also elsewhere on the board
/8086-processor/D14: U38.17 (D6); also elsewhere on the board
/8086-processor/D15: U38.18 (D7); also elsewhere on the board
/human-interfaces/V0: DS1.3 (V0), R21.2, R22.1
/~DIP_CS: U33.1; also elsewhere on the board
/~EVEN_7_SEG_CS: U32.5; also elsewhere on the board
/~LCD_CS: U32.11; also elsewhere on the board
/~LED_CS: U32.2; also elsewhere on the board
/~ODD_7_SEG_CS: U32.8; also elsewhere on the board
/~RD: U33.2; also elsewhere on the board
/~WR: U32.3, U32.6, U32.9, U32.12; also elsewhere on the board
GND: C37.2, C38.2, C39.2, C40.2, C41.2, DS1.1 (VSS), DS1.MH1, DS1.MH2, DS1.MH3, DS1.MH4, R22.2, SW26.1, SW26.2, SW26.3, SW26.4, SW26.5, SW26.6, SW26.7, SW26.8, U32.7 (GND), U33.4, U33.5, U33.7 (GND), U33.9, U33.10, U33.12, U33.13, U34.1 (OE), U34.10 (GND), U36.1 (OE), U36.10 (GND), U37.1 (CC), U37.6 (CC), U38.1 (OE), U38.10 (GND), U39.10 (GND), U40.1 (CC), U40.6 (CC); also elsewhere on the board
unnamed: D4.1 (K), RN1.16 (R1.2)
unnamed: D5.1 (K), RN1.15 (R2.2)
unnamed: D6.1 (K), RN1.14 (R3.2)
unnamed: D7.1 (K), RN1.13 (R4.2)
unnamed: D8.1 (K), RN1.12 (R5.2)
unnamed: D9.1 (K), RN1.11 (R6.2)
unnamed: D10.1 (K), RN1.10 (R7.2)
unnamed: D11.1 (K), RN1.9 (R8.2)
unnamed: DS1.6 (E), U32.13
unnamed: RN1.1 (R1.1), U34.2 (O0)
unnamed: RN1.2 (R2.1), U34.5 (O1)
unnamed: RN1.3 (R3.1), U34.6 (O2)
unnamed: RN1.4 (R4.1), U34.9 (O3)
unnamed: RN1.5 (R5.1), U34.12 (O4)
unnamed: RN1.6 (R6.1), U34.15 (O5)
unnamed: RN1.7 (R7.1), U34.16 (O6)
unnamed: RN1.8 (R8.1), U34.19 (O7)
unnamed: RN2.9 (R8.2), SW26.16, U39.2 (I0a)
unnamed: RN2.10 (R7.2), SW26.15, U39.4 (I1a)
unnamed: RN2.11 (R6.2), SW26.14, U39.6 (I2a)
unnamed: RN2.12 (R5.2), SW26.13, U39.8 (I3a)
unnamed: RN2.13 (R4.2), SW26.12, U39.11 (I0b)
unnamed: RN2.14 (R3.2), SW26.11, U39.13 (I1b)
unnamed: RN2.15 (R2.2), SW26.10, U39.15 (I2b)
unnamed: RN2.16 (R1.2), SW26.9, U39.17 (I3b)
unnamed: U32.1, U34.11 (Cp)
unnamed: U32.4, U36.11 (Cp)
unnamed: U32.10, U38.11 (Cp)
unnamed: U33.3, U39.1 (OEa), U39.19 (OEb)
unnamed: U36.2 (O0), U37.7 (DP)
unnamed: U36.5 (O1), U37.3 (G)
unnamed: U36.6 (O2), U37.2 (F)
unnamed: U36.9 (O3), U37.4 (E)
unnamed: U36.12 (O4), U37.5 (D)
unnamed: U36.15 (O5), U37.8 (C)
unnamed: U36.16 (O6), U37.9 (B)
unnamed: U36.19 (O7), U37.10 (A)
unnamed: U38.2 (O0), U40.7 (DP)
unnamed: U38.5 (O1), U40.3 (G)
unnamed: U38.6 (O2), U40.2 (F)
unnamed: U38.9 (O3), U40.4 (E)
unnamed: U38.12 (O4), U40.5 (D)
unnamed: U38.15 (O5), U40.8 (C)
unnamed: U38.16 (O6), U40.9 (B)
unnamed: U38.19 (O7), U40.10 (A)
VCC: C37.1, C38.1, C39.1, C40.1, C41.1, D4.2 (A), D5.2 (A), D6.2 (A), D7.2 (A), D8.2 (A), D9.2 (A), D10.2 (A), D11.2 (A), DS1.2 (VDD), R21.1, RN2.1 (R1.1), RN2.2 (R2.1), RN2.3 (R3.1), RN2.4 (R4.1), RN2.5 (R5.1), RN2.6 (R6.1), RN2.7 (R7.1), RN2.8 (R8.1), U32.14 (VCC), U33.14 (VCC), U34.20 (VCC), U36.20 (VCC), U38.20 (VCC), U39.20 (VCC); also elsewhere on the board

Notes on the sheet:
Power Decoupling
4x20 LCD Display 0xFFD0, 0xFFD2, 0xFFD4, 0xFFD6
8 LEDs 0xFFCC
Unused Gates
DIP Switches 0xFFCA
7-Segment Display 0xFFCE, 0xFFCF

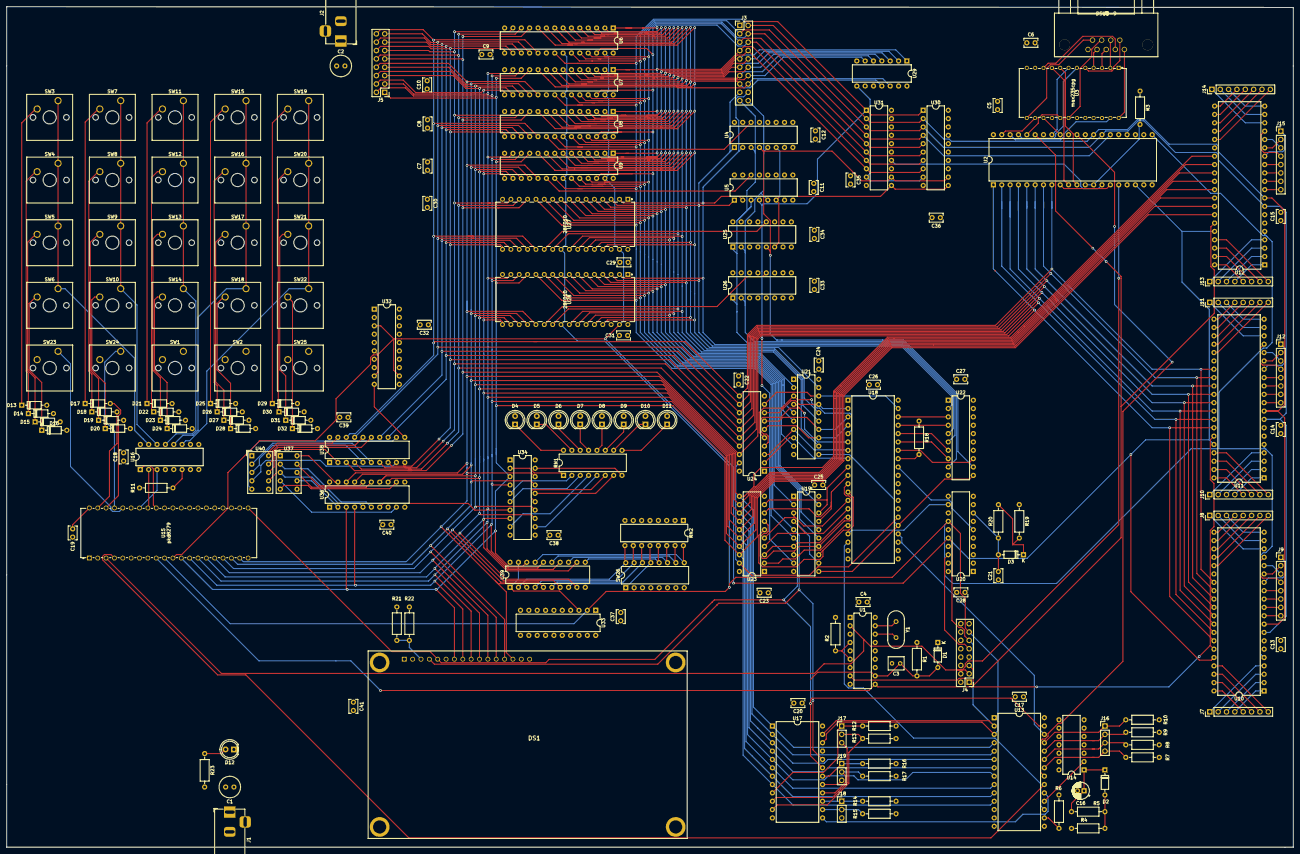
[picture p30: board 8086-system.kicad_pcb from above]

Board: 4 copper layers, 391.2 x 255.5 mm, 184 parts (0 on the bottom side), 294 nets.

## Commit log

2021-11-12 Inital commit/added requesite libraries
    [8086-system.kicad_pcb, 8086-system.sch]
2021-11-14 created 8086 processor block | created external connectors block
    [8086-processor.sch, 8086-system.sch, external-connectors.sch]
2021-11-15 created 8284A clock generator block
    [8086-system.sch, clock-generator.sch, external-connectors.sch]
2021-11-28 created 28F010 CMOS flash block; improved power decoupling; added M/~IO pin from 8086 sheet; reduced no. of logic gates in 8086 processor block; added +12V; moved input power to external-connectors s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
    [8086-processor.sch, 8086-system.sch, CMOS-flash.sch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]
2021-11-29 created 16550 UART interface block
    [8086-system.sch, UART-interface.sch]
2021-11-29 use more common type of switch for nmi
    [8086-processor.sch]
2021-11-30 fixed MWTC MRDC IOWC IORC decoding
    [8086-processor.sch]
2021-12-01 Add SRAM and PPIs
    [8086-processor.sch, 8086-system.sch, CMOS-flash.sch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]
2021-12-01 added 8279 keyboard block
    [8086-system.sch, 8279-keyboard.sch]
2021-12-01 Replaced MWTC MRDC IOWC IORC with WR RD; buffered control bus; consolidated logic gates
    [8086-processor.sch, 8086-system.sch, 8279-keyboard.sch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]
2021-12-02 Fix high/low byte on PPIs; Add counter and interrupt controller
    [8086-processor.sch, 8086-system.sch, 8279-keyboard.sch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]
2021-12-02 Fix disconnected WR/RD on PPIs
    [8086-processor.sch, 8086-system.sch, 8279-keyboard.sch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]
2021-12-02 Debounce pushbutton for 8259
    [8086-processor.sch, 8086-system.sch, interrupt-controller.sch]
2021-12-03 IO address decoding
    [8086-processor.sch, 8086-system.sch, 8279-keyboard.sch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]
2021-12-03 created human interface I/O devices
    [8086-system.sch, human-interfaces.sch]
2021-12-03 Fix wiring in root sheet
    [8086-processor.sch, 8086-system.sch, 8279-keyboard.sch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]
2021-12-04 Decode BHE for IO addresses
    [8086-system.sch, IO_addr_decode.sch]
2021-12-04 General edits; removed floating inputs
    [8086-processor.sch, 8086-system.sch, CMOS-flash.sch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]
2021-12-04 Updates to pass ERC
    [8086-processor.sch, 8086-system.sch, 8279-keyboard.sch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]
2021-12-06 Assign footprints for most symbols
    [8086-processor.sch, 8279-keyboard.sch, CMOS-flash.sch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]
2021-12-06 Assigned footprints
    [clock-generator.sch, external-connectors.sch, interrupt-controller.sch]
2021-12-08 assign footprints and edits
    [8086-processor.sch, 8279-keyboard.sch, external-connectors.sch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]
2021-12-09 begin pcb layout
    [8086-processor.sch, 8086-system.kicad_pcb, 8279-keyboard.sch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]
2021-12-10 Layout PPI, interrupt, counter, and UART blocks
    [8086-system.kicad_pcb]
2021-12-13 more traces routed
    [8086-system.kicad_pcb, 8279-keyboard.sch]
2021-12-13 Route some more, starting re-doing memory routing
    [8086-system.kicad_pcb, CMOS-flash.sch, peripheral-interface-odd.sch]
2021-12-13 continued pcb routing
    [8086-system.kicad_pcb]
2021-12-13 Route data bus lines, most chip selects
    [8086-system.kicad_pcb, IO_addr_decode.sch, human-interfaces.sch]
2021-12-14 more pcb routing
    [8086-system.kicad_pcb]
2021-12-14 Minor updates to silkscreen

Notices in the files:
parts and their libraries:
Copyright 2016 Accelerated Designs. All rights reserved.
